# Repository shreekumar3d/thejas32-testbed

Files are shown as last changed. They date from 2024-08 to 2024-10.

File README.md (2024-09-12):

# Status

We're at v1.0, and the board is being tested out.

Do look at the respective directories for hardware and software.

#  Intro

CDAC sells the [ARIES series of boards](https://vegaprocessors.in/devboards/) based on the [THEJAS32 microcontroller](https://vegaprocessors.in/soc/).
The boards can be programmed using the Arduino IDE. Unfortunately, the schematics
of these are not made available.  Documentation about the THEJAS32 SoC itself
is scarce as well, though the chip itself is available for [purchase on robu.in
in single quantity](https://robu.in/product/thejas32-soc-based-microprocessor/).

This project (and follow on work) will try to fill this gap, as I find more.
This is a board design for a learner board based on the THEJAS32
microcontroller. It is the first open source board based on 
the THEJAS32. This is part of a much larger effort to document THEJAS32 
and its ecosystem and make it usuable.

THEJAS32 runs directly on an external clock, offering a single core 100
MHz RISC-V CPU with a IO interfaces - UART, SPI, I2C, PWM and GPIOs.

This board sets up THEJAS32 a test microcontroller, controlled by a Raspberry
Pi Pico.  Some of the IO interfaces are routed to the Pico.  This opens
the door for many types of experimentation and learning, including clock
control, timing, peripheral emulation, etc.  

Useful background and goals for this board are well covered in my [recent talk
at IndiaFOSS 2024](https://youtu.be/-m1KqcOkT5M?t=6345) (video, 25 mins). There
is also a [AtiVEGA hackaday project](https://hackaday.io/project/197724-ativega) page.
Look at hackaday for updates, what's going on in the project, etc.

A somewhat detailed background and intro to the
board is also in [this presentation at ChennaiFOSS 2024 conference](https://www.youtube.com/watch?v=wljsP2YMgHc)
(video, 25 minutes) that I gave earlier this year.

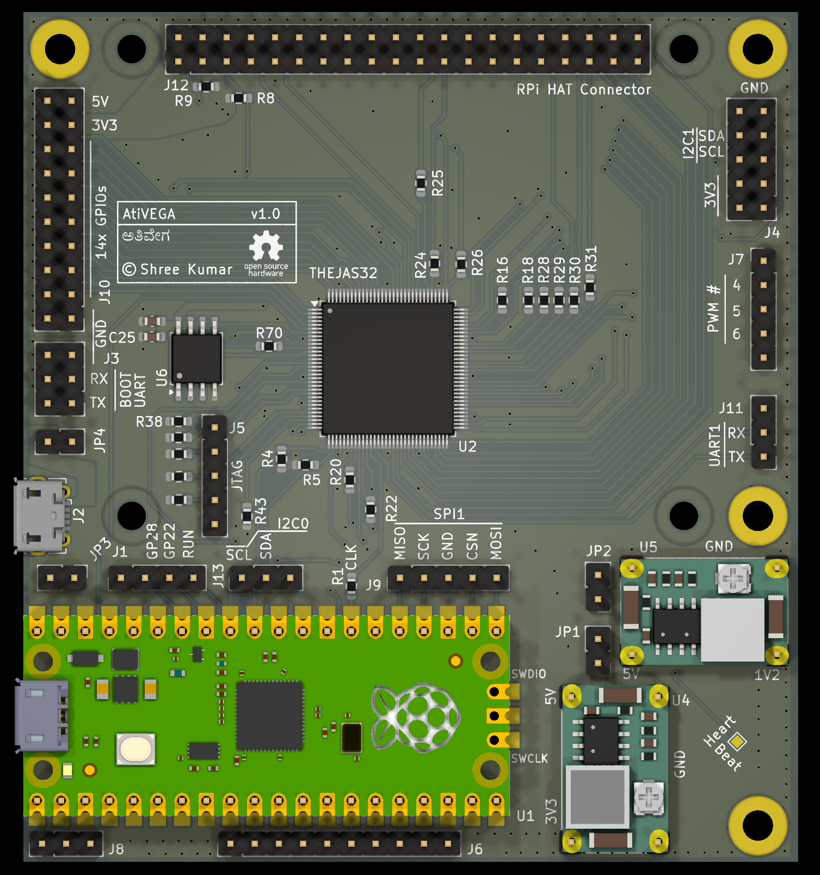
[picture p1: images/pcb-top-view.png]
PCB Top View


This board is designed to be a low cost board, relying on off-the-shelf components
as much as possible.  The goal is to encourage easy assembly without advanced
skills. For this reason, the smallest footprint chosen for passives is 0603.

# Design

The board consists of a few main elements

* THEJAS32 SoC
* 2 MB flash (used by THEJAS32)
* Raspberry Pi Pico
* 2x Mini 360 DC-DC power modules - one to generate core voltage of 1.2V, other for 3.3V

The core of the board consists of

* THEJAS32 SoC
* 2 MB flash

The power and boot cycle of the THEJAS32 ("MCU") is primarily controlled 
using a few pins

* active low RESET can be pulled up by Master Pico to get it out of reset
* System clock is generated from a GPOUT capable pin of the Pico. System 
  clock can thus be generated in many ways
* BOOT_SEL pin is controlled by Pico, allowing boot from SPI flash
  or UART.
* BOOT UART (UART0) is routed to Pico, enabling log capture and 
  programming

Pins and interfaces are broken out into standard 0.1" headers. Dual
row headers are mostly employed. When shorted, the interface gets routed from
the MCU to the RP2040. This enables advanced experimentation, precise timing,
peripheral emulation, co-processing, etc.

Board may be powered using the dedicated micro USB connector(J2) or through
the Pico.  Jumpers JP3 and JP4 decide the source of power. Both jumpers may
also be populated, allowing the Pico to function as a USB host, but care must
be taken not to connect Pico as a USB device in such cases. Refer to the schematic
for more info.

Precise measurement of power draw of the THEJAS32 is also a goal of this board. Jumpers JP2 and JP1 are included for this purpose.

# THEJAS32 IO

All IOs from THEJAS32 are broken out. Software can thus use all the pins. Some details are below; do refer the schematics for complete details.

## UART

Boot UART is available on J3. This can be sent to the Pico for control, by using two jumpers.

J11 breaks out UART1 from THEJAS32.

## Raspberry Pi HAT compatibility

Many Raspberry Pi HATs should be usable with this board, mounted on J12.
THEJAS32 does not have any pin multiplexing. The most commonly used 
functions on the various pins are thus directly assigned, including I2C,
SPI, UART and PWM and GPIOs. Refer the schematics for details.

A full size HAT can be mounted on this board. Additional through holes are 
provided to ensure mechanical support.

## GPIO Breakout

J10 features 14 GPIOs - GPIO17 to GPIO30. States for these can be set one shot, by bit masking.

## I2C and SPI

J4 breaks out I2C1 and SPI0.

J13 provides access to I2C0.  This is also connected to the Pico, for control. Pico can be setup as an I2C slave and respond to I2C transfers initiated by THEJAS32.

Similarly SPI1 is available on J9, also connected to SPI interface on Pico. Pico can be setup as a SPI slave, and respong to transfers initiated by THEJAS32.

## JTAG

J5 breaks out JTAG pins from THEJAS32.  Fun fact: none of the official ARIES boards break out JTAG.

## PWM

PWM pins 4,5,6 are broken out on J7. R32, R33 and R34 can be used to control the current.

# Raspberry Pi Pico

Pico controls the runtime lifecycle of the THEJAS32, via the RESET and CLK pins. BOOT_SEL is also under Pico's control. Note that the Pico is an integral part of the board design, as it provides the clock signal to THEJAS32.

J8 and J6 can be used to interface external electronics directly to Pico. J8 has the debug UART.

A single ADC pin, clock pin (GPIO22) are available as well.

# Tools

Based on KiCAD 8.

# Checkout Instructions

This project uses git submodules. To checkout everything, do:

    git clone --recurse-submodules https://github.com/shreekumar3d/thejas32-testbed.git

Raspberry Pi Pico footprint is a submodule.  If you don't go this, you'll not
see the nice Pico in the 3D preview.

# Credits

* [RPi Pico Symbool and Footprint](https://github.com/ncarandini/KiCad-RP-Pico)
* [Mini 360 Step Down Converter Footprint](https://github.com/rayvburn/KiCad)

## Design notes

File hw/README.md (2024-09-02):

# AtiVEGA Board

AtiVEGA is designed with KiCAD 8. The entire design is available here - both schematics and layout. Plus complete documentation, design rationale, etc.

High quality documentation is an important goal for this project. Obscurity is not. [THEJAS32](https://vegaprocessors.in/soc/) is a bit of a black box, and this is the tool to demistify it, learn from it and understand hardware at various levels. If you have a question, feel free to ask!

The *raison d'etre* of this board is to serve as a learning board for RISC-V at the PCB (board) level, the ISA level and the sillicon level.  It is designed for desk usage.

Raspberry Pi Pico is chosen as the system master for its excellent documentation, flexibility, capabilities and high performance. It is wired as a coprocessor, enabling many use cases.

As of this writing (September 2024), this is the only open source board that includes the THEJAS32.  Not just that - it is the only known board apart from CDAC's [ARIES boards](https://vegaprocessors.in/devboards/).  It is also the only board that breaks out the JTAG signals - the ultimate attempt to demistify the *Sarkaari* SoC! Open source trumps RTI (Right to Information) - FTW!

THEJAS32 is abbreviated to T32 in the rest of the document.

## PCB Design

The PCB is designed, and choice of components, is made to ease manual assembly.  That said, T32 - the main microcontroller, or more accurately, the *device under test(DUT)* has a LQFP128 footprint - with its pins spaced 0.5mm apart.  This is typically solderable with the aid of a magnifier.  The board also uses relatively fine surface mount components - resistors and capacitors are 0603.  The flash IC is an easier SOIC-8.  Rest are all through hole components - mostly connectors, the Raspberry Pi Pico and the Mini360 DCDC Power Modules.

The design emphasizes modularity, and relies on locally procurable components.  The idea is that anybody should be able to just get the PCB and the components and assemble the board. I could have included DC-DC regulators on the board, but I have chosen not to.  I believe this allows you to experiment with ease. Some examples:

 1. T32's core voltage is 1.2V and IO voltage is 3.3V.  Upper and lower limits are not know (yet!). Using the trimpot on the DCDC modules, these voltages can be changed. Not only will this allow me to find the limits (expecting magic smoke *at-least* once!), but it also allows anyone to study things like impact of system clock on power consumption, leakage current, etc.
 2. [Raspberry Pi Pico](https://www.raspberrypi.com/documentation/microcontrollers/pico-series.html) is used by default, but the board isn't specific to it, as there are a few compatbile options.  Need WiFi ? Use Pico W ! Need more performance - there's the Pico 2 now! Pico 2's selectable RISC-V/ARM cores means you can benchmark and compare two RISC-V implementations on one board - the [Hazard3 - RV32IMACZb*](https://github.com/Wren6991/Hazard3) and [ET1031 on T32 - RV32IM](https://vegaprocessors.in/thejas32.php). How cool is that ?

The PCB is designed as a 4 layer PCB, with the following layers:

 1. Signal - Top Layer
 2. GND
 3. Power
 4. Signal - Bottom Layer

# Simplified Schematics

For illustration, here is a simplified schematic. Some components or connectors are omitted for brevity.  They are explained later, as required.

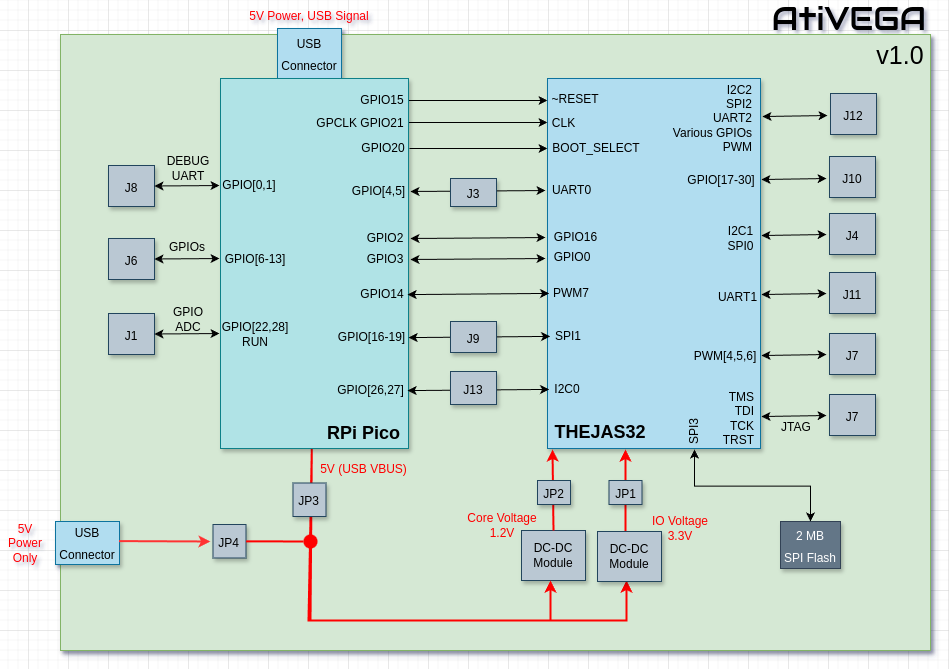
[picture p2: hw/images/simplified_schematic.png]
AtiVEGA Simplified Schematics


## Powering the Board

### Single Cable Operation

AtiVEGA can be powered by a single USB micro B cable, connected to the Pico. For this,

 1. Populate jumpers JP4, JP1 and JP2.
 2. Ensure JP3 is open

### Two Cable Operation

If you wish to measure the power consumed by the T32 section separately:

 1. Populate JP3, JP1 and JP2.
 2. Ensure JP4 is populated
 3. Connect both USB connectors to a host PC/5V power supply. Typically you would connect the Pico to a host PC for status monitoring, but this is strictly not essential.  You could choose to use J8 to monitor debug messages over UART.

Note that measuring power in series with JP3 will measure the power of T32, any components connected on the board (apart from the Pico), and it will include the overhead of the DCDC converters.

### Fine Grained Power Measurement

To avoid the DCDC connectors, you can connect a real power supply to the appropriate points on JP1(3.3V), JP2(1.2V) and JP3(5V).  This gives the most accurate power reading, at the cost of more equipment. Alternatively, just measure power in series using modules such as INA219.

## THEJAS32 <-> Pico

The Pico is the system master and a co-processor.  It is the first component on the board that powers on and becomes active.

The Pico is directly connected to T32's RESET_N, and CLK lines. GPIO21 is a GPCLK capable pin, and can drive T32's system clock at system clock speeds of the Pico - which is known to be massively overclockable...  How much can the T32 handle ?

T32 runs a bootloader from an internal bootrom (I am guessing, the bootrom part is not documented). The behaviour of this depends on the BOOT_SELECT line, which is controlled by the Pico.  If BOOT_SELECT is *low*, T32 loads code from the SPI flash (interface SPI3).  To support this, the board includes a 2MB SPI flash. If BOOT_SELECT is *high*, T32 boots from UART, using an XMODEM+CRC protocol.  T32's boot UART interface, UART0 is connected to GPIO4 and GPIO5 of the Pico, through the header JP3. This allows you to either tap out the lines for external examination, or route them to the Pico  the recommended default.

Note that irrespective of the state of BOOT_SELECT, T32 puts out the following fixed header over UART before taking action according to BOOT_SELECT.

    +-----------------------------------------------------------------------------+
    |           VEGA Series of Microprocessors Developed By C-DAC, INDIA          |
    |     Microprocessor Development Programme, Funded by MeitY, Govt. of India   |
    +-----------------------------------------------------------------------------+
    | Bootloader, ver 1.0.0 [  (hdg@cdac_tvm) Tue Dec  15 16:50:32 IST 2020 #135] |
    |                                                                             |
    |  ___    _________________________          ISA  : RISC-V [RV32IM]           |
    |  __ |  / /__  ____/_  ____/__    |                                          |
    |  __ | / /__  __/  _  / __ __  /| |         CPU  : VEGA ET1031               |
    |  __ |/ / _  /___  / /_/ / _  ___ |                                          |
    |  _____/  /_____/  \____/  /_/  |_|         SoC  : THEJAS32                  |
    +---------------------------------------+-------------------------------------+
    |         www.vegaprocessors.in         |             vega@cdac.in            |
    +---------------------------------------+-------------------------------------+

After T32 finishes booting, this UART can be used to communicate between the applications running on the T32 and the Pico.

GPIO[0,16] of T32 are routed to GPIO[2,3] of Pico.  These can be used to intimate each other of actions to be taken.  As a simple example, T32 could use GPIO0 to control the LED on the Pico, with the Pico's involvement. Similarly, the on-board button on the Pico could be used to take appropriate action on T32. Note that proper usage will require setting the appropriate direction on both sides of the GPIO.

T32's PWM7 pin is routed to Pico's GPIO14.  This can be used to test, validate and characterize the PWM capabilities of the T32.  Additionally, as a PWM with 100% duty cycle, it can be used as a GPIO output from T32 to Pico.

Similarly, T32's SPI1 and I2C0 interfaces are also routed to Pico.  T32's hardware interfaces are master only.  Luckily, Pico supports slave modes for both SPI and I2C. With appropriate software, Pico can even emulate actual hardware, and even initiate external action (over USB or WiFi/BT in case of Pico W).

Since the board uses standard headers, you can even use jumper wires to connect other IOs between Pico and T32.

Overall, many useful possibilities are created by these interconnections, and these  will be further explored in the 'sw' directory.

## External Hardware Connections to THEJAS32

### GPIOs

14 GPIOs - GPIO[17-30] are available on J10 (it also includes 3.3V, 5V and GND).

These GPIOs are chosen for a specific purpose - they are controlled by a single register, thus their states may be changed/sampled with a single instruction. 

When used as output, GPIO16 (connected to Pico) and GPIO31 (on the HAT connector) could also be impacted by the instruction, and appropriate care can be taken if needed.

### UART

T32's UART1 interface is routed to J11.

### I2C

T32's I2C1 interface is connected to J4.  Pull up resistors R6 and R7 are on the bottom side of the board.

### SPI

T32's SPI0 interface is routed to J4. Series resistors R16 and R18 for clock and MOSI line are placed close to T32 on the top side, for tuning, if necessary.

### PWM

3 PWM pins, PWM 4,5 and 6 are routed to J7. R32, R33 and R34 are series resistors on these lines. T32's pins support 12mA per IO pin, which is sufficient to drive LEDs. Ensure you use appropriate current limiting resistors, or replace the ones on the board.

### Raspberry Pi HAT compatibility

Raspberry Pi HATs can be plugged in to J12 and used. pHATs and full sized HATs are mechanically compatible.  For full sized HATs, two through holes are provided for mechanical support and grounding.

T32 does not have any kind of pin multiplexing.  Thus, this board cannot support all the pin multiplexing as implemented on a Raspberry Pi. That said, I have looked at the most common uses of the pins in HATs (from [pinout.xyz](https://pinout.xyz/)), and pins have been assigned to maximize compatibility.  Most commonly used functions on specific pins (I2C and SPI) have been included.

Here is the detailed pin mapping:

|RPi Pin Mapping |T32 Pin  |HAT Pin No|HAT Pin No|T32 Pin |RPi Pin Mapping |
|---|---|---|---|---|---|
|3V3 Power | | 1 | 2 | |5V Power |
|GPIO 2(I2C1 SDA)  |I2C2_SDA | 3 | 4 | |5V Power |
|GPIO 3(I2C1 SCL)  |I2C2_SCL | 5 | 6 | |Ground |
|GPIO 4(GPCLK0) |GPIO 31  | 7 | 8 |UART2_TX|GPIO 14(UART TX)  |
|Ground | | 9 | 10 |UART2_RX|GPIO 15(UART RX)  |
|GPIO 17 |GPIO 1 | 11 | 12 |PWM0 |GPIO 18(PCM CLK)  |
|GPIO 27 |GPIO 2 | 13 | 14 | |Ground |
|GPIO 22 |GPIO 3 | 15 | 16 |GPIO 4  |GPIO 23 |
|3V3 Power | | 17 | 18 |GPIO 5  |GPIO 24 |
|GPIO 10(SPI0 MOSI)|SPI2_MOSI| 19 | 20 | |Ground |
|GPIO 9(SPI0 MISO) |SPI2_MISO| 21 | 22 |GPIO 6  |GPIO 25 |
|GPIO 11(SPI0 SCLK)|SPI2_CLK | 23 | 24 |SPI2_CSN|GPIO 8(SPI0 CE0)  |
|Ground | | 25 | 26 |GPIO 7  |GPIO 7(SPI0 CE1)  |
|GPIO 0(EEPROM SDA)|GPIO 8 | 27 | 28 |GPIO 9  |GPIO 1(EEPROM SCL)|
|GPIO 5 |GPIO 10  | 29 | 30 | |Ground |
|GPIO 6 |GPIO 11  | 31 | 32 |PWM1 |GPIO 12(PWM0) |
|GPIO 13(PWM1) |PWM2 | 33 | 34 | |Ground |
|GPIO 19(PCM FS) |PWM3 | 35 | 36 |GPIO 12 |GPIO 16 |
|GPIO 26 |GPIO 13  | 37 | 38 |GPIO 14 |GPIO 20(PCM DIN)  |
|Ground | | 39 | 40 |GPIO 15 |GPIO 21(PCM DOUT) |

HAT's EEPROM SDA and SCL are connected to T32 GPIO 8 and 9. I am not sure if EEPROM is used extensively.  If required, I2C access would need to be achieved via bit banging these pins. There are no pull-up options on the board to facilitate this, though. Should be enough for EEPROM, though.

A large number of HATs/pHATs use I2C, and some use SPI (common for displays). These should be largely compatible.  For a complete compatibility list, check the end of this document.

## External Hardware Connections to Pico

Unused pins on the Pico are broken out into specific headers to ease interfacing with external hardware.

### Debug UART

Pico's GPIO0 and 1 are connected to J8.  These are typically used as the debug UART pins on the Pico - supported by hardware uart0.

### GPIOs

8 GPIOs - GPIO 6-13 are routed to J6, with their pins directly in-line with the Pico. These can be used to interface external hardware in any number of flexible ways.

Similarly, GPIO22 and GPIO28 are routed to J1.

### ADC

Pico's GPIO28 can be used as an ADC pin - and it is broken out to J1.

# RPi HAT/pHAT Compatibility

Here is a hardware compatibility table for HATs from [pinout.xyz](https://pinout.xyz).

Note that this is not an indicator of software support.  The Tested column should be your definitive guide.  If you test something and it works, do let me know!

I have a few HATs and pHATs, which I will test and update below. This table mostly reflects grunt work I do that I don't want to waste.

|SN |Manufacturer |HAT Name |Form Factor|Compatible|Tested?|Notes |
|---|---|---|---|---|---|---|
|1  |AB Electronics UK|1 Wire Pi Plus |HAT |Yes | | |
|2  |AB Electronics UK|1 Wire Pi Zero |pHAT |Yes | | |
|3  |Adafruit |16x2 Character LCD |pHAT |Yes | | |
|4  |Waveshare |2.13 Inch E-Ink Display pHAT |pHAT |Yes | | |
|5  |PlasmaDan |30 A Relay HAT |HAT |Yes | | |
|6  |PiHut |3D XMAS Tree |HAT |No | | |
|7  |Sixfab |3G/4G/LTE Base Shield |HAT |Yes | | |
|8  |Sixfab |3G/4G/LTE Base Shield V2 |HAT |No | |UART pin mismatch |
|9  |AB Electronics UK|ADC Differential Pi |pHAT |Yes | | |
|10 |AB Electronics UK|ADC Pi |pHAT |Yes | | |
|11 |AB Electronics UK|ADC-DAC Pi Zero |pHAT |Yes | | |
|12 |Google |AIY Vision Bonnet |pHAT |Unknown | |Check again |
|13 |Google |AIY Voice Bonnet |pHAT |No | |No I2S support |
|14 |Google |AIY Voice HAT |HAT |No | |No I2S support |
|15 |JustBoom |Amp HAT |HAT |No | |No I2S support |
|16 |JustBoom |Amp Zero |pHAT |No | |No I2S support |
|17 |RasPIO |Analog Zero |pHAT |Yes | | |
|18 |PlasmaDan |Appliance HAT |HAT |Yes | | |
|19 |PlasmaDan |Appliance HAT Mini |pHAT |Yes | | |
|20 |Adafruit |Arcade Bonnet |pHAT |No | |No I2S support |
|21 |Pimoroni |Audio Amp SHIM |pHAT |No | |No I2S support |
|22 |Pimoroni |Automation HAT |HAT |Possible  | |Use PWM as GPIO |
|23 |Pimoroni |Blinkt! |pHAT |No | |Check again |
|24 |Pimoroni |Breakout Garden HAT |HAT |Yes | |Check again |
|25 |Pimoroni |Breakout Button SHIM |pHAT |Yes | | |
|26 |PiHut |CamJam EduKit 3 motor controller board |pHAT |Yes | |Check GPIO usage |
|27 |Josip Medved |Canaka |HAT |Yes | | |
|28 |Adafruit |Capacitive Touch HAT |HAT |Yes | | |
|29 |Paser |Carberry |HAT |No | |LIRC pin |
|30 |Sixfab |Raspberry Pi Cellular IoT Application HAT|HAT |No | |UART pin mismatch |
|31 |ModMyPi |Christmas Tree Star | |No | |SPI pins can't be used as GPIO |
|32 |Element14 |Cirrus Logic Audio Card |HAT |No | |No audio support |
|33 |Google |Coral Environment Sensing Board |pHAT |No | |PWM pin can't be used as GPIO input|
|34 |PlasmaDan |CTRL HAT |HAT |Yes | | |
|35 |4tronix |cube:bit Base |HAT |No | |PWM pin can't do neopixel timing |
|36 |JustBoom |DAC HAT |HAT |No | |No audio support |
|37 |JustBoom |DAC Zero |pHAT |No | |No audio support |
|38 |Adafruit |DC & Stepper Motor HAT |HAT |Yes | | |
|39 |Raspihats |DI6acDQ6rly I2C-HAT |HAT |Yes | | |
|40 |JustBoom |Digi HAT |HAT |No | |No audio support |
|41 |JustBoom |Digi Zero |pHAT |No | |No audio support |
|42 |Kertatuote |Disco HAT | |No | |PWM pin can't be used as GPIO input|
|43 |Pimoroni |Display HAT Mini |pHAT |Maybe | |Use GPIO 7 as SPI CS |
|44 | | | | | | |

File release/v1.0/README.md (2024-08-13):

This is the first gerber release to production.

I am excited as this will be my second personal PCB, ever! The first one was an
automatic water control design for drip irrigation, built with the MSP430.

After some comparisons, I ended up using JLCPCB for the manufacturing. Gave them
ativega-v1.zip. Opted for impedance control, and no marks on the PCB. Also
included the production confirmation for peace of mind.

The top view, bottom view of the PCB generated by JLCPCB, as well as the
manufacturing gerbers are in the corresponding directory.

The first batch is 10 boards. $30.90 for boards, $35.20 for shipping, totalling
$66.10.

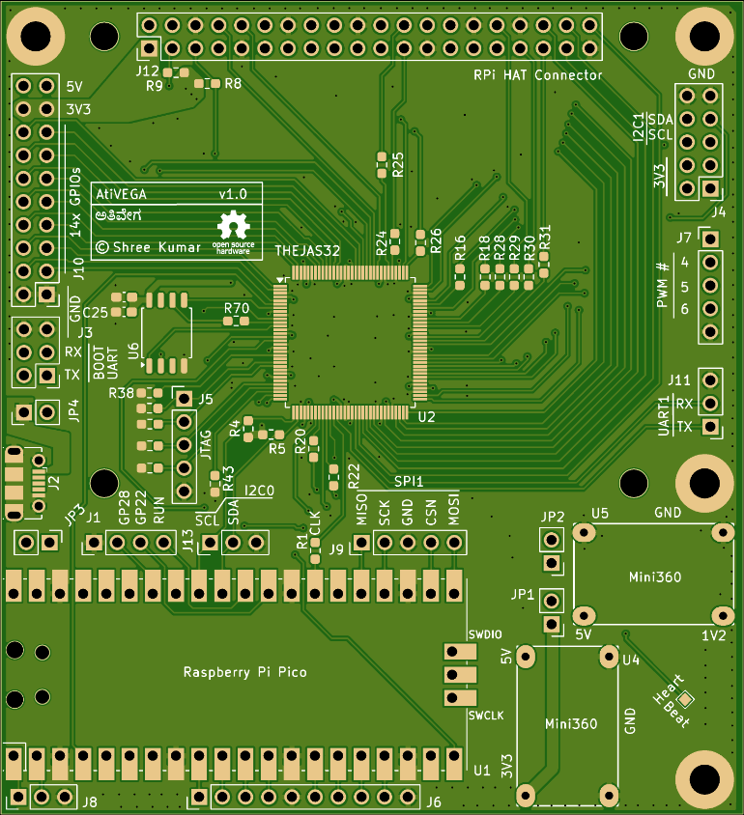
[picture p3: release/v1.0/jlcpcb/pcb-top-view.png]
Top View


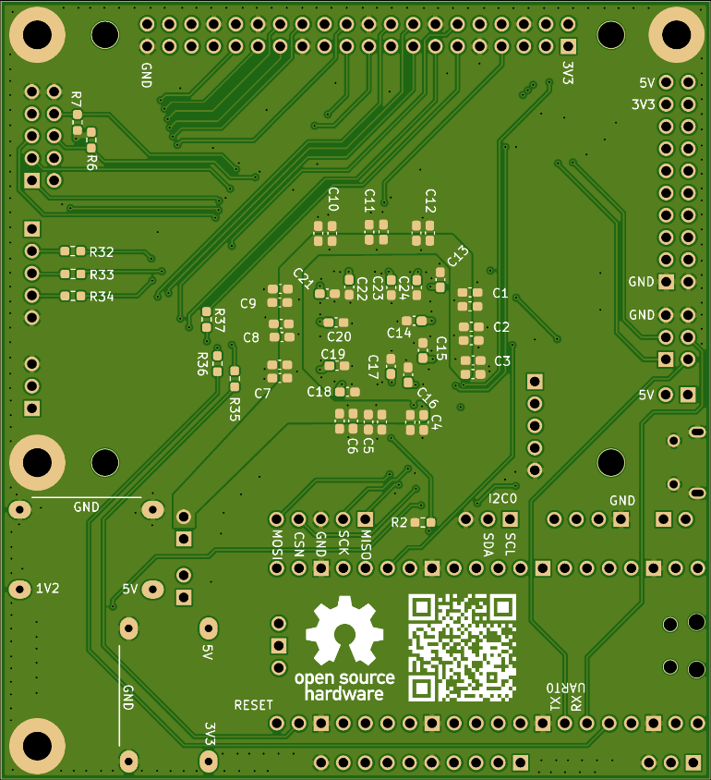
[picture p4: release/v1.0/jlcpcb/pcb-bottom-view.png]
Bottom View


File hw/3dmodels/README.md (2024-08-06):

MicroUSB connector Molex 105017-0001
3dmodel : 1050170001.stp
Source : https://www.molex.com/en-us/products/part-detail/1050170001

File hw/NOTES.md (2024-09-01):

Hardware is designed with KiCAD v8.

If kicad complains about missing freemono font, install the package
fonts-freefont-ttf

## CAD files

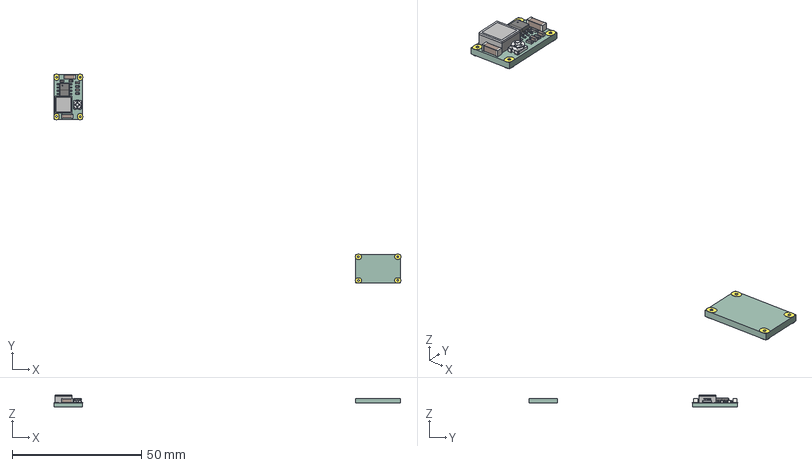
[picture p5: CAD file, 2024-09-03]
hw/3dmodels/mini360-model.step
134.4 x 80.9 x 4.63 mm
C_0603_1608Metric
R_0603_1608Metric
R_0603_1608Metric001
R_0603_1608Metric002
C_0603_1608Metric001
C_0603_1608Metric002
C_1806_4516Metric001
mini360_pad_1 x 2
mini360_pad_2 x 2
mini360_pad_3 x 2
mini360_pad_4 x 2
mini360_pad_5 x 2
mini360_pad_6 x 2
mini360_pad_7 x 2
mini360_pad_8 x 2
mini360_pad_9 x 2
mini360_pad_10 x 2
mini360_pad_11 x 2
mini360_pad_12 x 2
mini360_PCB x 2
C_1806_4516Metric
EVM-3E
729b0bae-9266-11ed-9e62-a0cec80452fd_part x 4
729b0e92-9266-11ed-9e62-a0cec80452fd_part x 5
729b0e92-9266-11ed-9e62-a0cec80452fd_part001 x 5
729b0e92-9266-11ed-9e62-a0cec80452fd_part002 x 5
729b0e92-9266-11ed-9e62-a0cec80452fd_part003 x 5
729b0e92-9266-11ed-9e62-a0cec80452fd_part004 x 5
729b0e92-9266-11ed-9e62-a0cec80452fd_part005 x 5
729b0e92-9266-11ed-9e62-a0cec80452fd_part006 x 5
729b0e92-9266-11ed-9e62-a0cec80452fd_part007 x 5
729b1108-9266-11ed-9e62-a0cec80452fd_part x 4

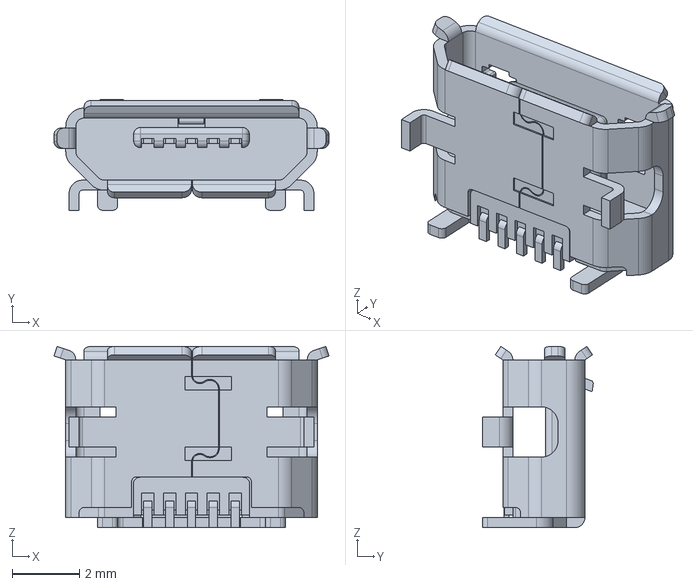
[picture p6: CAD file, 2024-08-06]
hw/3dmodels/1050170001.stp
8.20 x 3.30 x 5.40 mm

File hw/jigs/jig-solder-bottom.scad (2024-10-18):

// Auto generated file by jig-gen, the awesome automatic
// jig generator for your PCB designs.
//
// Input board file   : ../thejas32-testbed/hw/thejas32-testbed.kicad_pcb
// Configuration file : ../thejas32-testbed/hw/jigs/solder-bottom.toml
//
// Complete configuration file is embedded at the end of this
// file.

// { These are configurable parameters
// you can tweak these here and count on
// openscad magic to do show you the result
// right away!

// Tesellate finer than 3D printer can print
$fs = 0.05;

// Gap for components to slide into their shell,
// on all sides in the horizontal plane (in mm)
shell_gap = 0.1;
                
// Thickness of shells (in mm)
shell_thickness = 0.8;

// Thickness of PCB (in mm)
pcb_thickness=1.8;

// Clearance between typical shells and PCB
// Allows you to check and confirm component fit
shell_clearance=1.0;

// Shells jet out of the PCB by this much
// (Mostly a visualization/debug aid)
shell_protrude=1;

// Thickness of base (in mm)
// base provides a holding structure for the shells
// and connects it to the frame (on which the board
// sits)
base_thickness = 1.0;

// Line width in the mesh
mesh_line_width = 1.6;

// By default, we generate a base with a delaunay
// frame holding the shells together.
//
// Sometimes you just need a solid base - e.g. to
// put some text - like PCB info, version
// and even stuff like qrcodes! For these you
// mostly need a solid base. Set this is non-zero
// if that's what you need.
base_is_solid = 0;

// Board will sit on a lip, close to mounting holes
// Lips that lie in a square of this size (in mm)
// will be part of the model.
lip_size=15;

// Gap (in mm) between board edge and slot on which the board sits
pcb_gap=0.3;

// Width of the lip (in mm) on which the board rests
pcb_overlap=0.5;

// PCB holder's wall thickness (in mm)
// This will be the thickness after the gap
pcb_holder_perimeter=1.6;

// The board can have a (lower) perimeter for added
// strength/aesthetics.  Perimeter height is above
// the base, and in mm
pcb_perimeter_height = 2;

// } End of configurable parameters

// { START : Computed Values

// Height of the tallest component on the top side
topmost_z=8.53948;
// Height of the individual components
max_z_J7_0=8.53948; //3D Model: ${KICAD8_3DMODEL_DIR}/Connector_PinHeader_2.54mm.3dshapes/PinHeader_1x05_P2.54mm_Vertical.wrl
max_z_J5_0=8.53948; //3D Model: ${KICAD8_3DMODEL_DIR}/Connector_PinHeader_2.54mm.3dshapes/PinHeader_1x05_P2.54mm_Vertical.wrl
max_z_J9_0=8.53948; //3D Model: ${KICAD8_3DMODEL_DIR}/Connector_PinHeader_2.54mm.3dshapes/PinHeader_1x05_P2.54mm_Vertical.wrl
max_z_J1_0=8.53948; //3D Model: ${KICAD8_3DMODEL_DIR}/Connector_PinHeader_2.54mm.3dshapes/PinHeader_1x04_P2.54mm_Vertical.wrl
max_z_J3_0=8.53948; //3D Model: ${KICAD6_3DMODEL_DIR}/Connector_PinHeader_2.54mm.3dshapes/PinHeader_2x03_P2.54mm_Vertical.wrl
max_z_J6_0=8.53948; //3D Model: ${KICAD8_3DMODEL_DIR}/Connector_PinHeader_2.54mm.3dshapes/PinHeader_1x10_P2.54mm_Vertical.wrl
max_z_JP3_0=8.53948; //3D Model: ${KICAD8_3DMODEL_DIR}/Connector_PinHeader_2.54mm.3dshapes/PinHeader_1x02_P2.54mm_Vertical.wrl
max_z_JP2_0=8.53948; //3D Model: ${KICAD6_3DMODEL_DIR}/Connector_PinHeader_2.54mm.3dshapes/PinHeader_1x02_P2.54mm_Vertical.wrl
max_z_J13_0=8.53948; //3D Model: ${KICAD8_3DMODEL_DIR}/Connector_PinHeader_2.54mm.3dshapes/PinHeader_1x03_P2.54mm_Vertical.wrl
max_z_U5_0=8.53948; //3D Model: ${KICAD8_3DMODEL_DIR}/Connector_PinHeader_2.54mm.3dshapes/PinHeader_1x01_P2.54mm_Vertical.wrl
max_z_U5_1=8.53948; //3D Model: ${KICAD8_3DMODEL_DIR}/Connector_PinHeader_2.54mm.3dshapes/PinHeader_1x01_P2.54mm_Vertical.wrl
max_z_U5_2=8.53948; //3D Model: ${KICAD8_3DMODEL_DIR}/Connector_PinHeader_2.54mm.3dshapes/PinHeader_1x01_P2.54mm_Vertical.wrl
max_z_U5_3=8.53948; //3D Model: ${KICAD8_3DMODEL_DIR}/Connector_PinHeader_2.54mm.3dshapes/PinHeader_1x01_P2.54mm_Vertical.wrl
max_z_U4_0=8.53948; //3D Model: ${KICAD8_3DMODEL_DIR}/Connector_PinHeader_2.54mm.3dshapes/PinHeader_1x01_P2.54mm_Vertical.wrl
max_z_U4_1=8.53948; //3D Model: ${KICAD8_3DMODEL_DIR}/Connector_PinHeader_2.54mm.3dshapes/PinHeader_1x01_P2.54mm_Vertical.wrl
max_z_U4_2=8.53948; //3D Model: ${KICAD8_3DMODEL_DIR}/Connector_PinHeader_2.54mm.3dshapes/PinHeader_1x01_P2.54mm_Vertical.wrl
max_z_U4_3=8.53948; //3D Model: ${KICAD8_3DMODEL_DIR}/Connector_PinHeader_2.54mm.3dshapes/PinHeader_1x01_P2.54mm_Vertical.wrl
max_z_J12_0=8.53948; //3D Model: ${KICAD6_3DMODEL_DIR}/Connector_PinHeader_2.54mm.3dshapes/PinHeader_2x20_P2.54mm_Vertical.wrl
max_z_J2_0=2.5749970500000003; //3D Model: ${KIPRJMOD}/3dmodels/1050170001.wrl
max_z_JP4_0=8.53948; //3D Model: ${KICAD8_3DMODEL_DIR}/Connector_PinHeader_2.54mm.3dshapes/PinHeader_1x02_P2.54mm_Vertical.wrl
max_z_J8_0=8.53948; //3D Model: ${KICAD8_3DMODEL_DIR}/Connector_PinHeader_2.54mm.3dshapes/PinHeader_1x03_P2.54mm_Vertical.wrl
max_z_JP1_0=8.53948; //3D Model: ${KICAD6_3DMODEL_DIR}/Connector_PinHeader_2.54mm.3dshapes/PinHeader_1x02_P2.54mm_Vertical.wrl
max_z_J10_0=8.53948; //3D Model: ${KICAD6_3DMODEL_DIR}/Connector_PinHeader_2.54mm.3dshapes/PinHeader_2x10_P2.54mm_Vertical.wrl
max_z_J4_0=8.53948; //3D Model: ${KICAD8_3DMODEL_DIR}/Connector_PinHeader_2.54mm.3dshapes/PinHeader_2x05_P2.54mm_Vertical.wrl
max_z_J11_0=8.53948; //3D Model: ${KICAD8_3DMODEL_DIR}/Connector_PinHeader_2.54mm.3dshapes/PinHeader_1x03_P2.54mm_Vertical.wrl
max_z_U1_1=7.00024; //3D Model: ${KICAD8_3DMODEL_DIR}/Connector_PinSocket_2.54mm.3dshapes/PinSocket_1x20_P2.54mm_Vertical.wrl
max_z_U1_2=7.00024; //3D Model: ${KICAD8_3DMODEL_DIR}/Connector_PinSocket_2.54mm.3dshapes/PinSocket_1x20_P2.54mm_Vertical.wrl
// } END : Computed Values
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

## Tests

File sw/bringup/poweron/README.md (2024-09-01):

# Basic Power On Test

This sample does a basic power on the THEJAS32 on the AtiVEGA board.  The RP2040 microcontroller on the Pico serves as the driver.

## AtiVEGA Architecture

AtiVEGA includes the THEJAS32 microcontroller and a Raspberry Pi Pico.  

Typical microcontrollers use a medium frequency crystal (few MHz) as a clock source. They include an internal oscillator and PLL to boost this frequency manifold.  Raspeberry Pi Pico is based on the RP2040 microcontroller.  This microcontroller runs at 125 MHz or more, using a PLL running from a 12 MHz crystal.

Unlike the RP2040, THEJAS32 need an oscillator capable of driving a 3.3V clock! ARIES boards include a dedicated oscillator, part number [SIT8008AC-33-33E-100.000000](https://www.sitime.com/parts/sit8008ac-73-33e-100000000) for this purpose.  This generates the system clock for THEJAS32 - a fixed 100 MHz.  If we do include this part, we would adds to the cost and power consumption of AtiVEGA. We can do better than that.

Instead of a discrete oscillator, we use the a GPCLOCK pin of the RP2040 as the clock source.  This pin can be driven by the RP2040 at a very high speed. How fast ? At a maximum rate of the system clock of the RP2040. That's 125 MHz typical.  And more, if you overclock the microcontroller.

AtiVEGA also connect the RESET pin and BOOT_SELECT of THEJAS32 to RP2040 GPIO pins.  THEJAS32 checks tthe BOOT_SELECT pin on power up.  If it is low, the chip boots from the SPI flash.  If it is high, the chip boots from UART.  In either cases, THEJAS32 uses the boot UART to show the status and/or provide the option of uploading code.

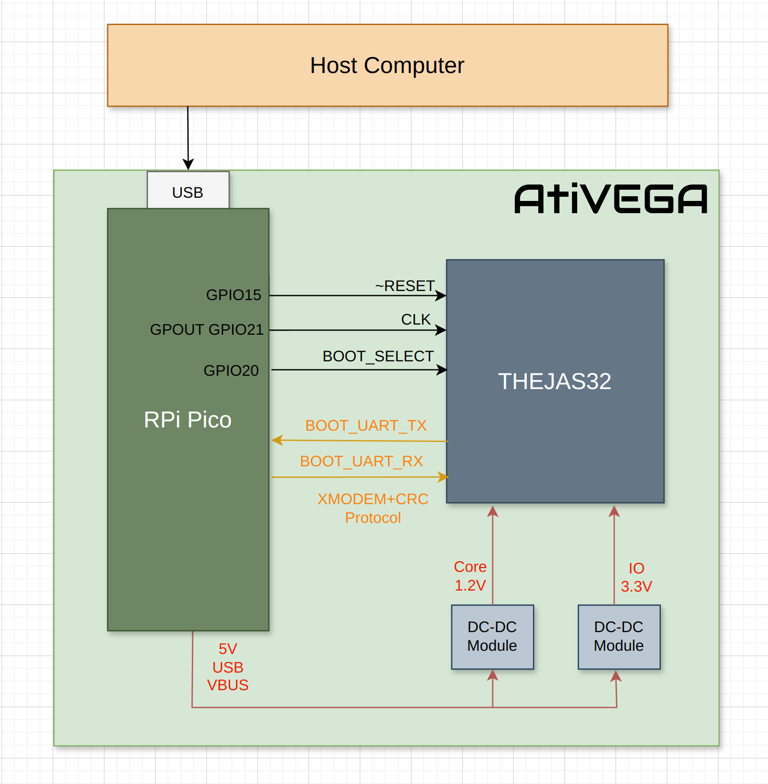
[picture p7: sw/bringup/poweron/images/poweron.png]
Power On Board Schematic


Overall, THEJAS32 runtime life cycle is controlled by RP2040 in the Pico.  And hence, the entire lifecycle is software driven. And you can control it.  This sample shows how.

## Source Code

This is a Pico C/C++ SDK project.  When you build it, you will get poweron.uf2. Push it into the Pico to activate it.

poweron.c has all the power on steps mentioned below.  It is well commented. System clock is configured in CMakeLists.txt, which is also the build script for the project.

## Power On Method

Before powering on, first connect GPIO30 on header J10 to 3.3V with a jumper.  THEJAS32 uses this to configure the baud rate of the Boot UART interface.

Pico will restart and start running the code.  First, THEJAS32 is placed in reset by setting the GPIO low.  BOOT_SELECT line is pulled high to indicate UART boot. Then a 100 MHz clock is provided via GPIO21.  THEJAS32 is then taken out of reset, by setting the GPIO high.

In response, THEJAS32 boots.  First, it prints out a header. Then it waits for a software image over UART. This project does not implement the capability of uploading a software image.  Only basic booting is illustrated.

You can use your favourite terminal emulator (e.g. minicom) to look at the UART activity. If you see messages like below - then congratulations, you did everything right !

    =========================================================
    AtiVEGA ready to power-on THEJAS32
    Communicating with THEJAS32 at UART baud=195312
                                  (requested:195312)
    Powering on with clock=100000000 Hz _after_ 3 seconds!
    THEJAS32's boot log will follow after the next line
    =========================================================

    +-----------------------------------------------------------------------------+
    |           VEGA Series of Microprocessors Developed By C-DAC, INDIA          |
    |     Microprocessor Development Programme, Funded by MeitY, Govt. of India   |
    +-----------------------------------------------------------------------------+
    | Bootloader, ver 1.0.0 [  (hdg@cdac_tvm) Tue Dec  15 16:50:32 IST 2020 #135] |
    |                                                                             |
    |  ___    _________________________          ISA  : RISC-V [RV32IM]           |
    |  __ |  / /__  ____/_  ____/__    |                                          |
    |  __ | / /__  __/  _  / __ __  /| |         CPU  : VEGA ET1031               |
    |  __ |/ / _  /___  / /_/ / _  ___ |                                          |
    |  _____/  /_____/  \____/  /_/  |_|         SoC  : THEJAS32                  |
    +---------------------------------------+-------------------------------------+
    |         www.vegaprocessors.in         |             vega@cdac.in            |
    +---------------------------------------+-------------------------------------+

    Transfer mode  : UART XMODEM

    IRAM           : [0x200000 - 0x23E7FF] [250 KB]

    Please send file using XMODEM and then press ENTER key.

    ==> Ready to receive image 66275 microseconds after power on.
    ==> First char was received 6 microseconds after power on.

    CCCCCCCCCCCCCCCCCCCCCCCCCCCCCCCCCCCCCCCCCCCC

Note that the two lines beginning with "==>" are printed by this project's code.  Everything else above is output by THEJAS32 over UART.

## Slowing down THEJAS32

THEJAS32's clock speed can be *reduced* by changing T_CLK_DIV in poweron.c. A divider of 2 will run THEJAS32 at 50 MHz, 4 at 25 MHz, and 40 at 2.5 MHz.  Higher the divider, lower the execution speed.  You'll see the UART text slowly coming up as you increase the divider.  Note that changing the clock will indirectly change the UART baud rate as well.

How low can you go ?

## Overclocking THEJAS32

THEJAS32 is described as a 100 MHz RISC-V microcontroller.  But how fast can it really run ?

How about a cool 172 MHz ? Check CMakeLists.txt, rebuild, flash and enjoy!

## Monitoring the Heart Beat

THEJAS32 has a unique debugging feature - a HEART BEAT pin. CDAC's ARIES boards connect an LED to that.  AtiVEGA doesn't - we just route it to a pad on the board. This pin toggles at a very slow rate compared to the system clock - around 2.5 Hz with a 100 MHz system clock.  This is a 3.3V signal, and can be viewed with a simple logic analyzer (salea logic or clones) or an oscilloscope.

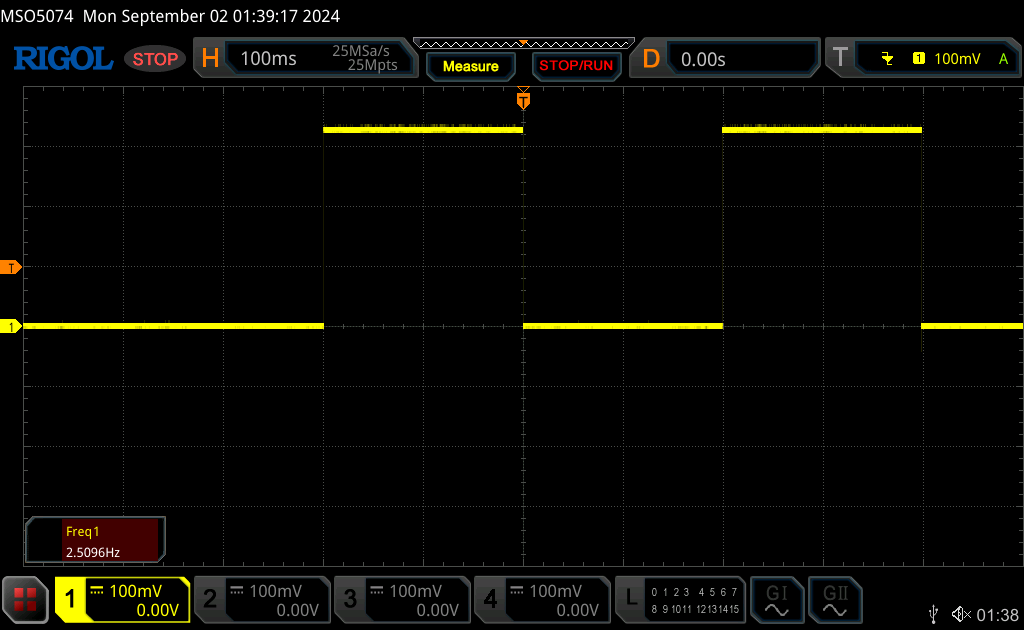
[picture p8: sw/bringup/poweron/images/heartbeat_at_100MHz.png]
Heart Beat signal with system clock=100 MHz


In hindsight, I should have made it at-least a through hole pin to make it easier to connect to the RP2040 with a jumper wire. Perhaps in the second revision....

## Lab Exercises

Work out these...

 1. What's the slowest clock speed at which you can run THEJAS32 ?
 2. What is the fastest clock speed at which you can run THEJAS32 ?
 3. Do you see UART messages at the slowest/fastest clock rate you were able to manage ? If not, why not ? And how would you fix the program to see the messages ?
 4. I suspect there is a constant relationship (divider) between THEJAS32 clock and the HEART BEAT signal. Can you find this ? Is this the same across boards ?
 5. What is the power consumption of only the THEJAS32 ? How does it relate to the clock speed ?

# One Last Thing!

If you don't connect GPIO30 to 3.3V, there is a good chance you won't see any messages on UART.  This is required due to an annoying design decision taken by whoever designed the bootloader of the THEJAS32 (and burnt it into ROM!).

The bootloader samples a whopping 7 GPIOs - GPIO31 to GPIO25.  Essentially, this is converted to a divider in the range 0 to 127.  The bootloader configures a UART baud rate equal to Sytem Clock/(16 x value). The ARIES boards pull up/down these GPIOs to set a baud rate of 115200.  Unfortunately, AtiVEGA doesn't.  So, if you don't connect a jumper, the divisor could become 0, effectively disabling UART messages. It can be really confusing when that happens. So, do populate the jumper.  With that, the bootloader will *mostly* set a baud rate of 195312.  There I said it, *mostly* !

Even with the jumper, on rare occasions, you won't see any messages coming from THEJAS32.  As the other GPIOs are "floating" rather than pulled down, there is a chance that THEJAS32 will sample one or more of them as high.  This will result in actual baud rate selected by THEJAS32 to be very different than what the RP2040 thinks it is.  Due to the baud rate mismatch, you won't see the messages.

Without spinning the board, hwo can this be handled ? Can you think of a scheme to automagically detect the baud rate of THEJAS32 from the RP2040 ? The good news is yes, you can. Look at the poweron_autobaud bringup sample for details.

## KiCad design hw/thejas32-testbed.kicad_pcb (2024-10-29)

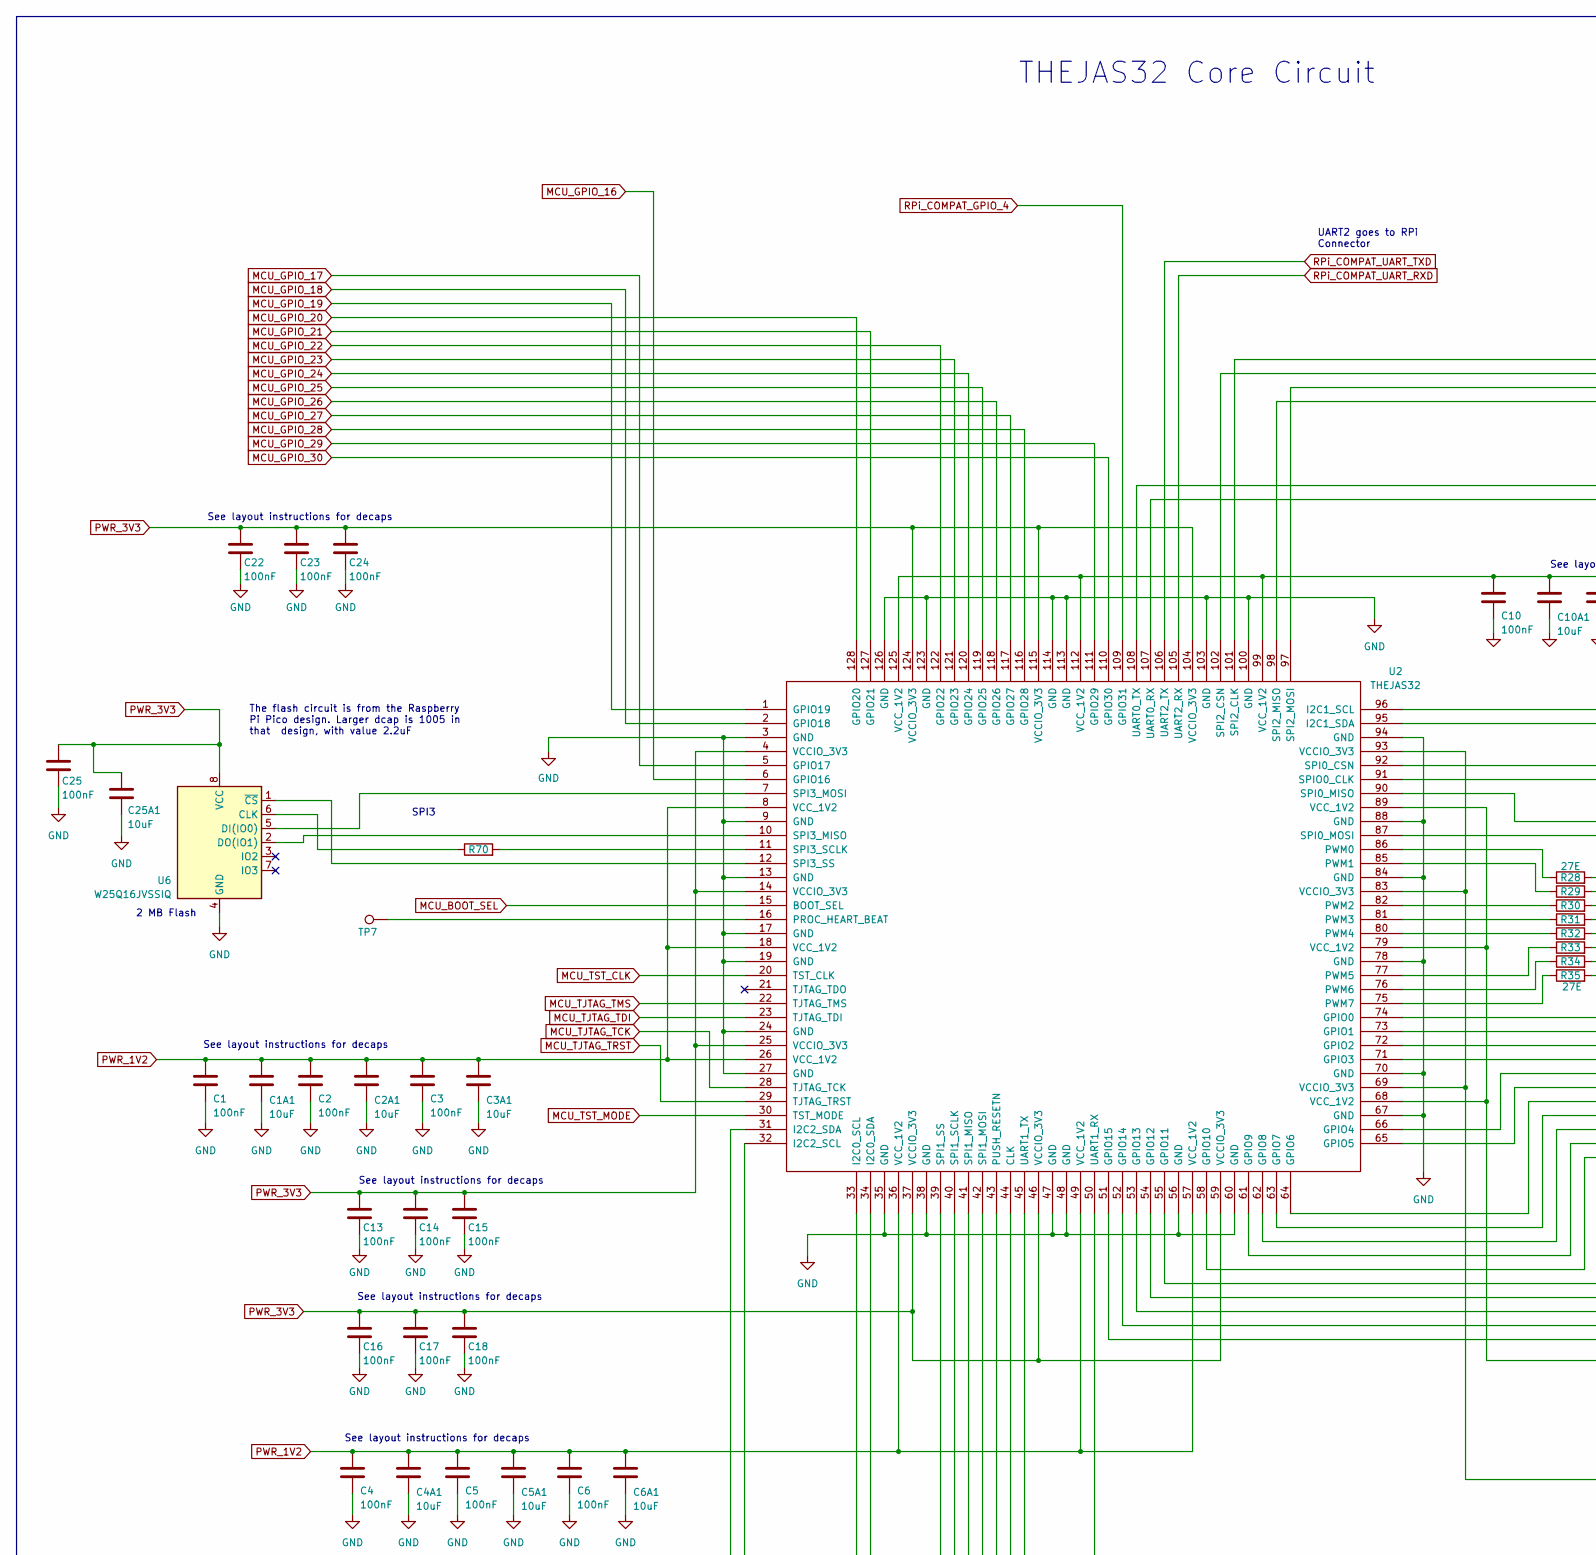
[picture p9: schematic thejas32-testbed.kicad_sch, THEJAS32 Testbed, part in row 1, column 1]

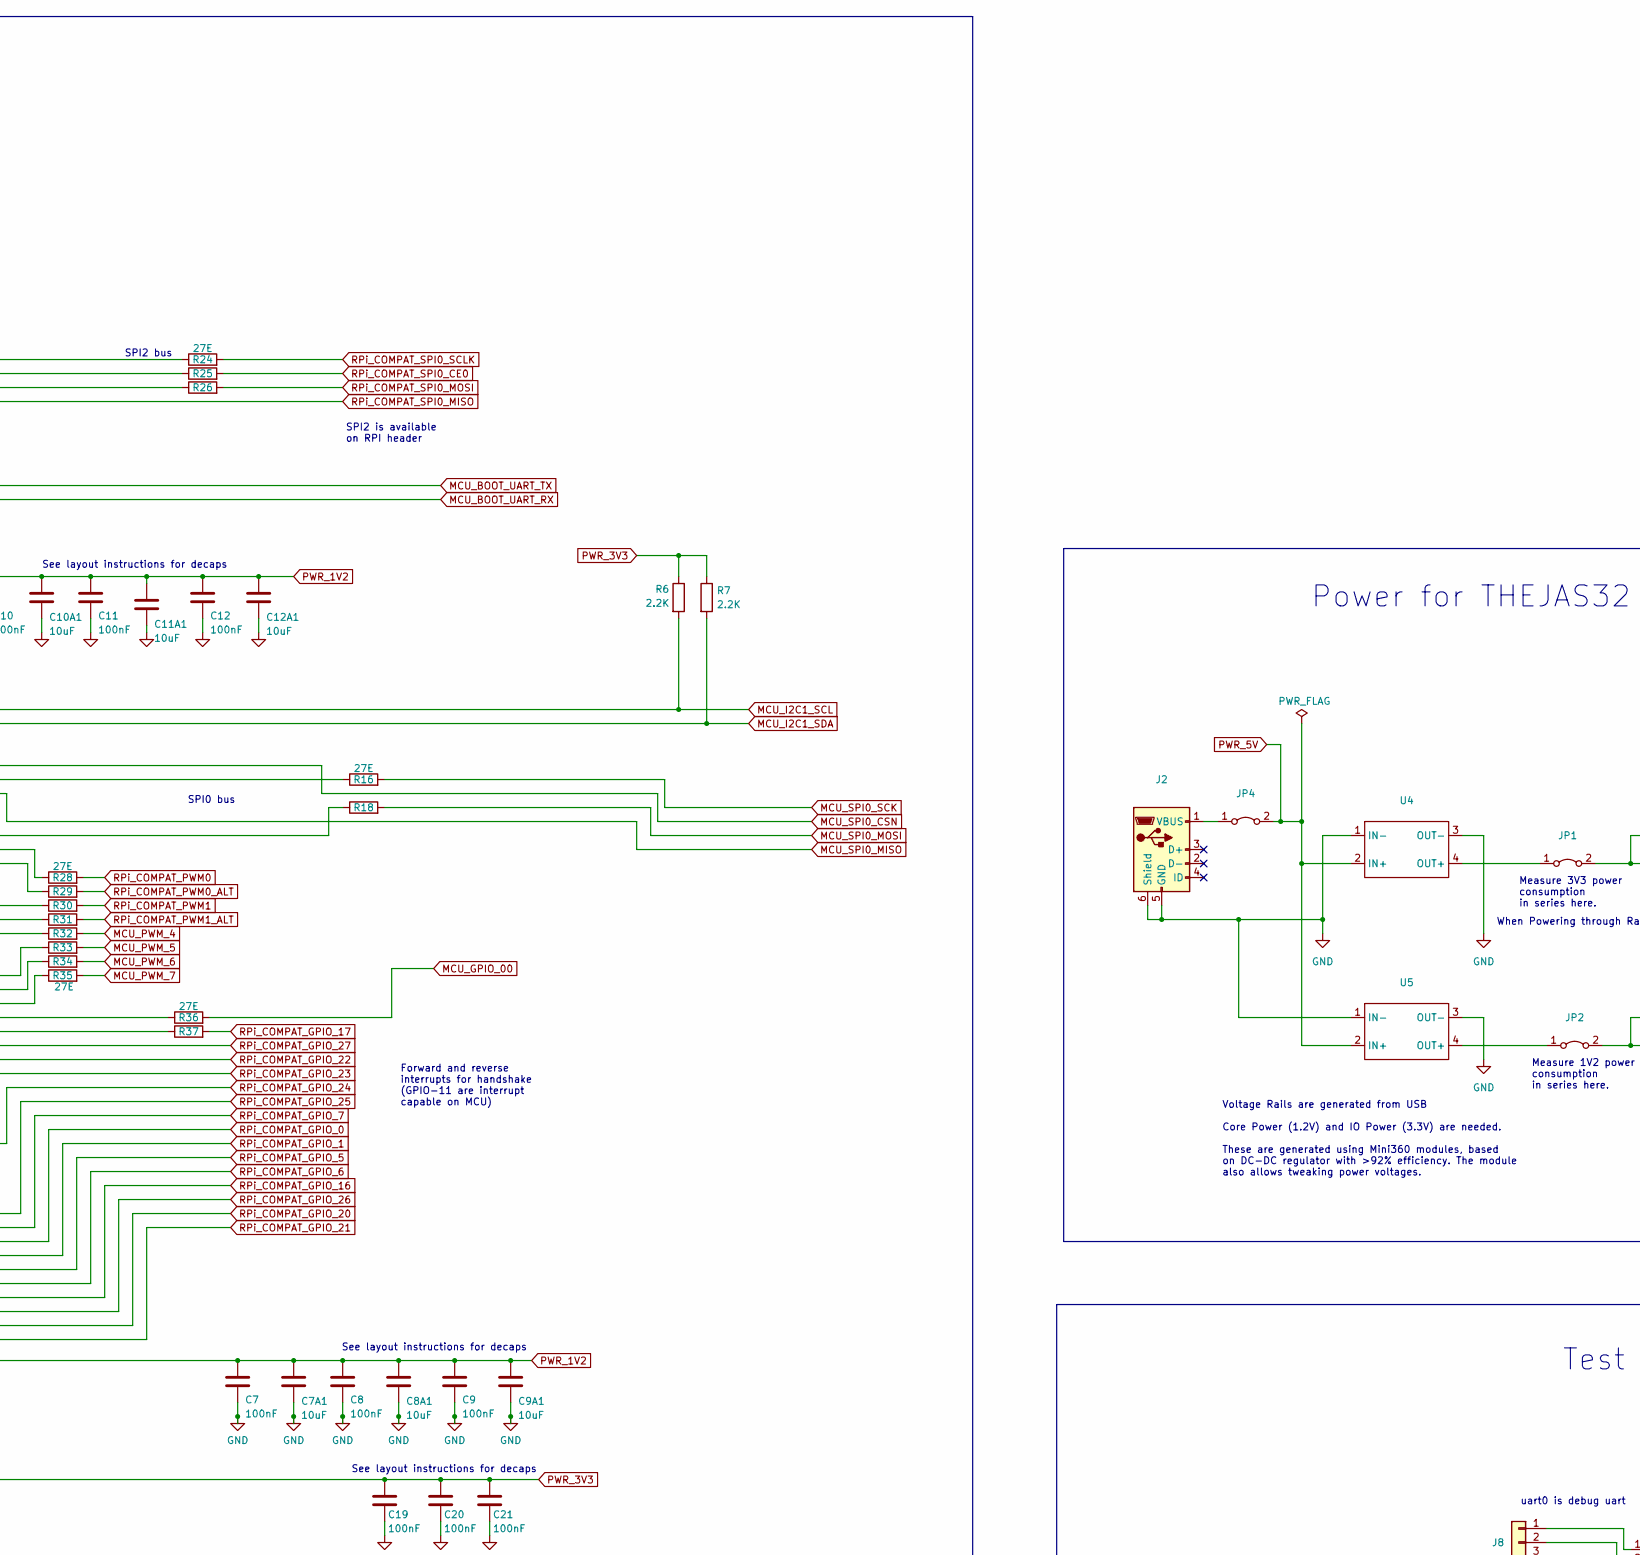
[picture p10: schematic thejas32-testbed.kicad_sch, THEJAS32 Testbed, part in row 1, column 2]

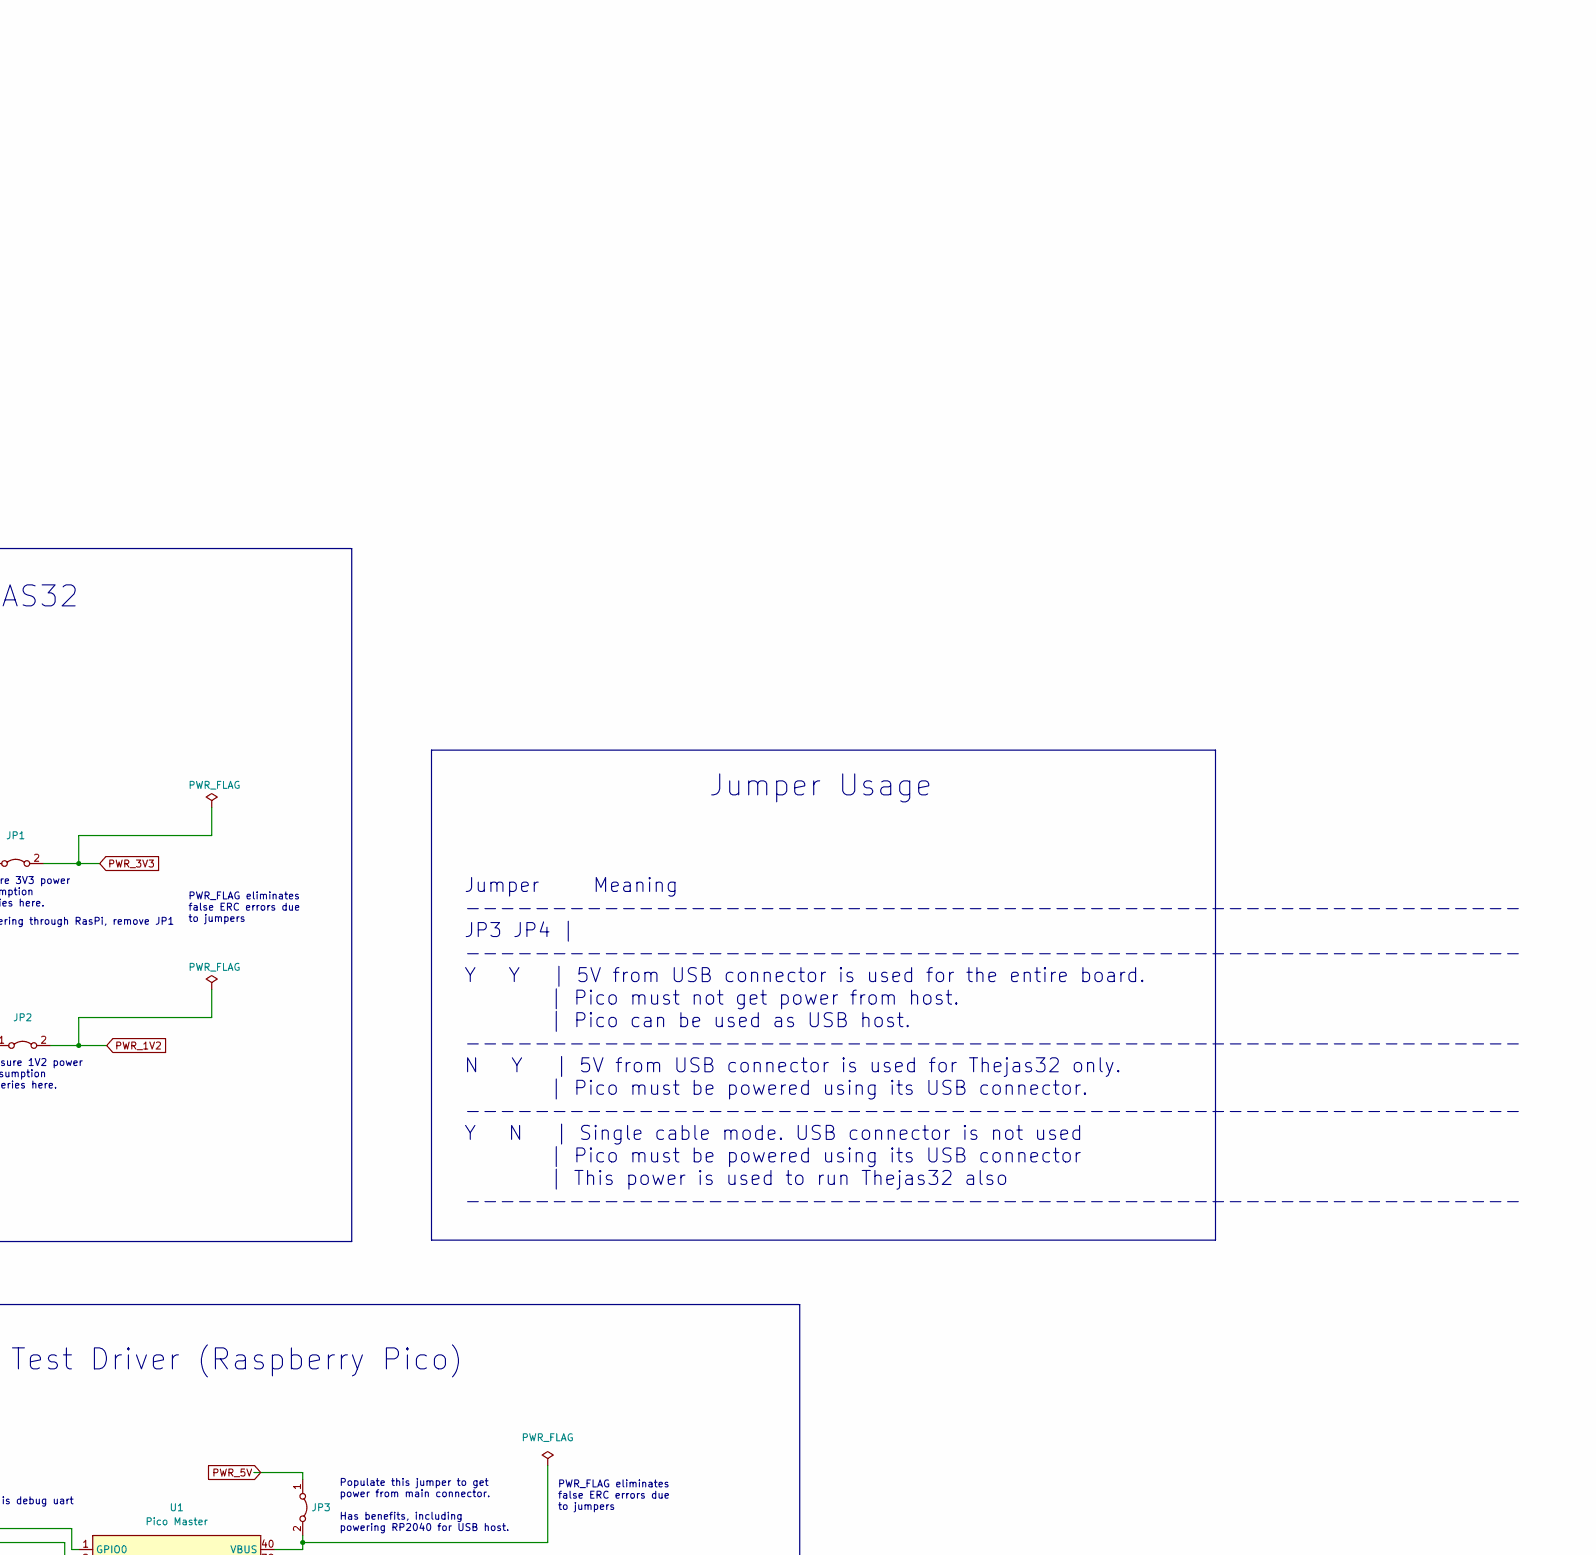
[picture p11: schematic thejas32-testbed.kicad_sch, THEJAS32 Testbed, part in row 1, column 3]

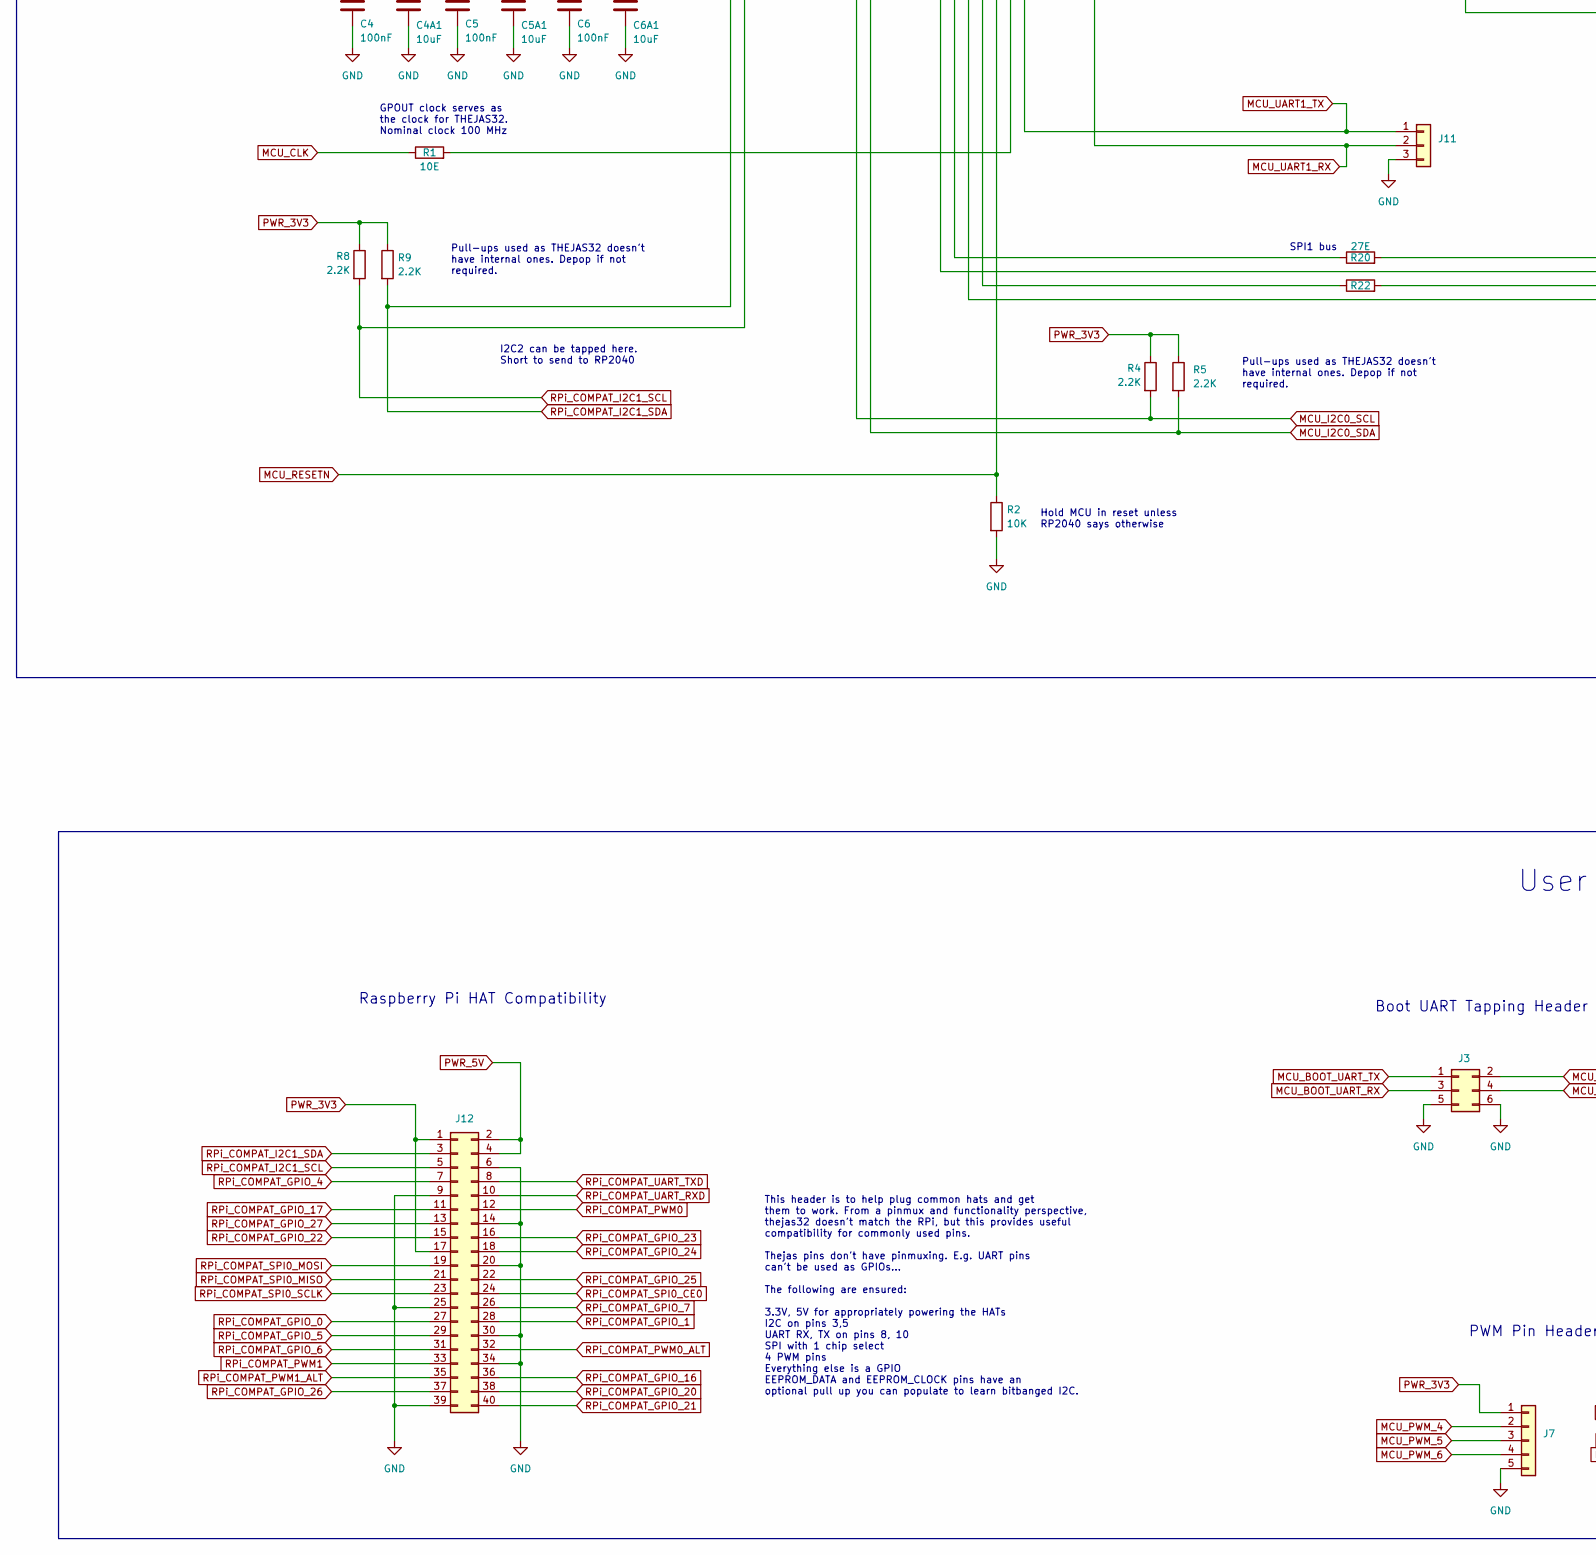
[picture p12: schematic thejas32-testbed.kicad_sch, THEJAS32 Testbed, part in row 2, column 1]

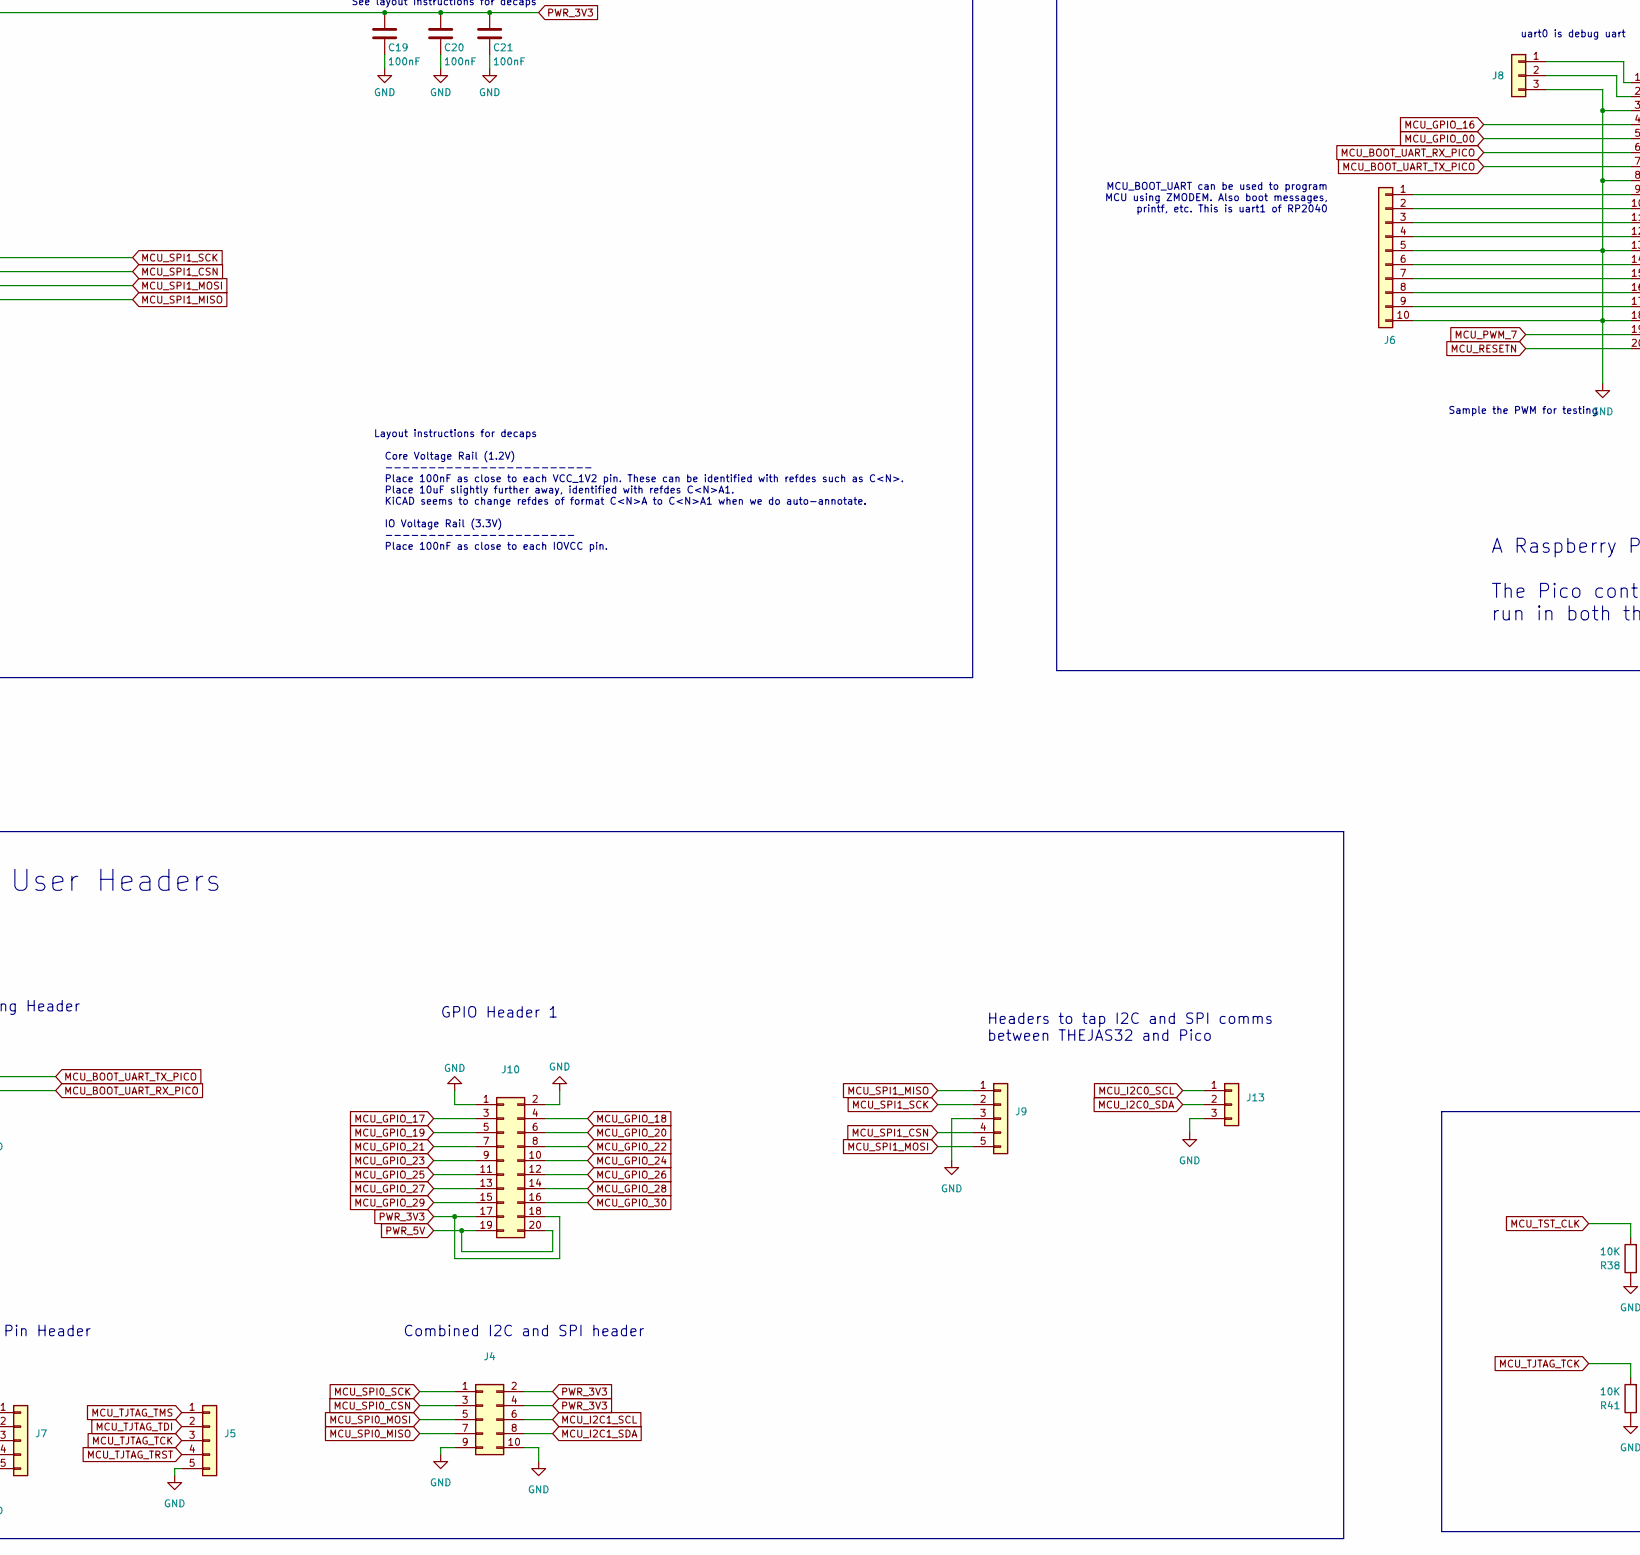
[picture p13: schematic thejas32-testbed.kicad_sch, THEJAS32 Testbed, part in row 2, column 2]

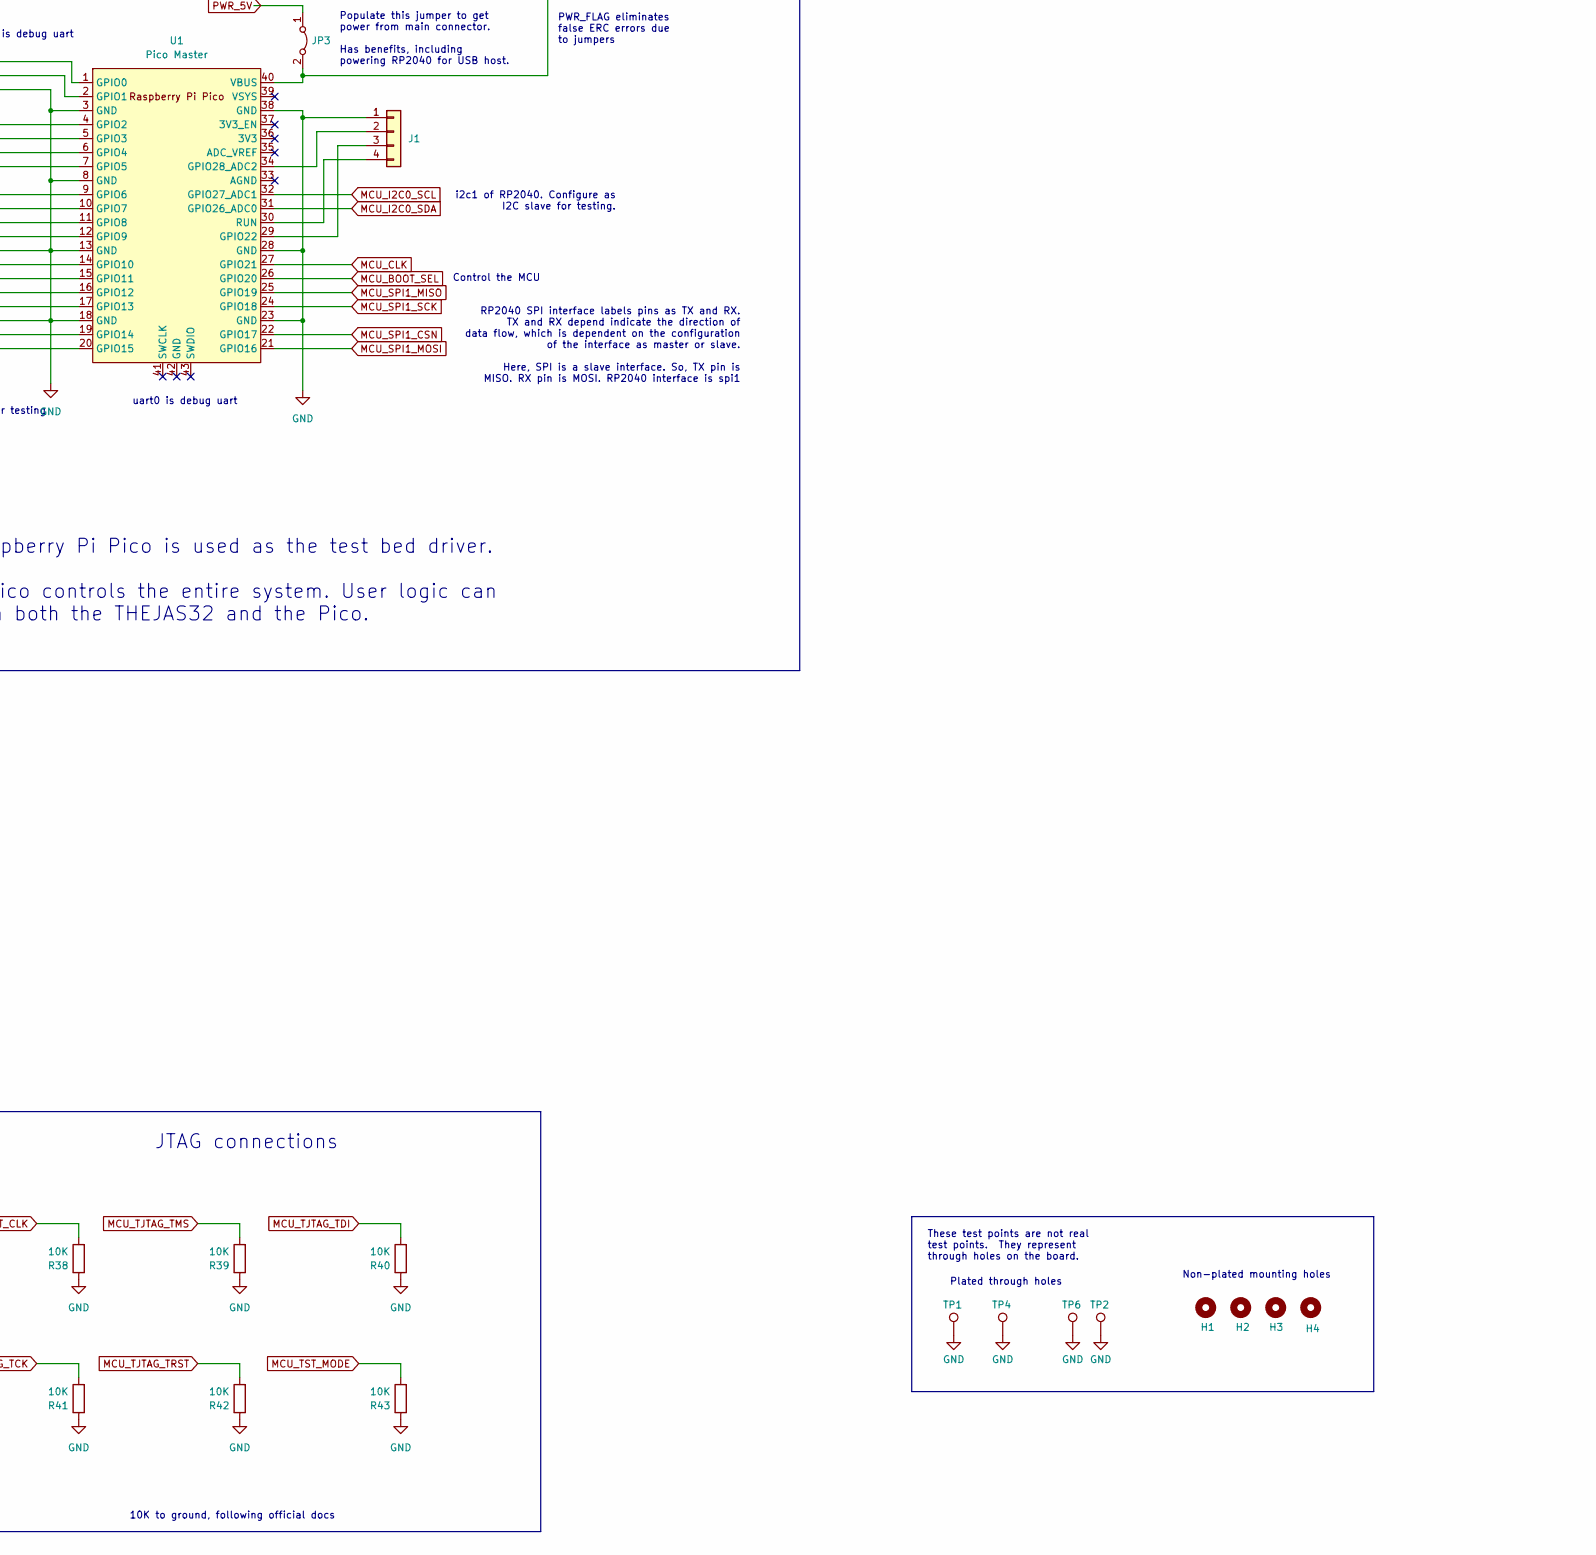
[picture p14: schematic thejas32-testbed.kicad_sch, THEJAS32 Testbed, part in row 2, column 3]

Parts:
C1, C2, C3, C4, C5, C6, C7, C8, C9, C10, C11, C12, C13, C14, C15, C16, C17, C18, C19, C20, C21, C22, C23, C24, C25: 100nF; proj_C_0603_1608Metric_Pad1.08x0.95mm_HandSolder; MPN 5190
C1A1, C2A1, C3A1, C4A1, C5A1, C6A1, C7A1, C8A1, C9A1, C10A1, C11A1, C12A1, C25A1: 10uF; proj_C_0603_1608Metric_Pad1.08x0.95mm_HandSolder; MPN 6799
H1, H2, H3, H4: MountingHole; MountingHole_3mm
J1: Conn_01x04; PinHeader_1x04_P2.54mm_Vertical; MPN 2.54 mm 1x4 pin male header
J2: USB_B_Micro; USB_Micro-B_Molex-105017-0001; MPN 4653
J3: Conn_02x03_Odd_Even; PinHeader_2x03_P2.54mm_Vertical; MPN 2.54 mm 2x3 pin male header
J4: Conn_02x05_Odd_Even; PinHeader_2x05_P2.54mm_Vertical; MPN 2.54 mm 2x5 pin male header
J5, J7, J9: Conn_01x05; PinHeader_1x05_P2.54mm_Vertical; MPN 2.54 mm 1x5 pin male header
J6: Conn_01x10; PinHeader_1x10_P2.54mm_Vertical; MPN 2.54 mm 1x10 pin male header
J8, J11, J13: Conn_01x03; PinHeader_1x03_P2.54mm_Vertical; MPN 2.54 mm 1x3 pin male header
J10: Conn_02x10_Odd_Even; PinHeader_2x10_P2.54mm_Vertical; MPN 2.54 mm 2x10 pin male header
J12: Conn_02x20_Odd_Even; PinHeader_2x20_P2.54mm_Vertical; MPN 2.54 mm 2x20 pin male header
JP1, JP2, JP3, JP4: Jumper_2_Bridged; PinHeader_1x02_P2.54mm_Vertical; MPN 2.54 mm 1x2 pin male header
R1, R70: 10E; proj_R_0603_1608Metric_Pad0.98x0.95mm_HandSolder; MPN 5354
R2, R38, R39, R40, R41, R42, R43: 10K; proj_R_0603_1608Metric_Pad0.98x0.95mm_HandSolder; MPN 5192
R4, R5, R6, R7, R8, R9: 2.2K; proj_R_0603_1608Metric_Pad0.98x0.95mm_HandSolder; MPN 6735
R16, R18, R20, R22, R24, R25, R26, R28, R29, R30, R31, R32, R33, R34, R35, R36, R37: 27E; proj_R_0603_1608Metric_Pad0.98x0.95mm_HandSolder; MPN 5297
TP1, TP2, TP4, TP6: Mounting Hole; MountingHole_3.2mm_M3_Pad_TopBottom
TP7: TestPoint; TestPoint_Pad_1.0x1.0mm
U1: Pico Master; RPi_Pico_SMD_TH; MPN Raspberry Pi Pico
U2: THEJAS32; LQFP-128_14x14mm_P0.4mm; MPN THEJAS32
U4, U5: Mini360_step-down; MPN 790469
U6: W25Q16JVSSIQ; SOIC-8_5.23x5.23mm_P1.27mm; MPN W25Q16JVSSIQ

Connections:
GND: C1.2, C1A1.2, C2.2, C2A1.2, C3.2, C3A1.2, C4.2, C4A1.2, C5.2, C5A1.2, C6.2, C6A1.2, C7.2, C7A1.2, C8.2, C8A1.2, C9.2, C9A1.2, C10.2, C10A1.2, C11.2, C11A1.2, C12.2, C12A1.2, C13.2, C14.2, C15.2, C16.2, C17.2, C18.2, C19.2, C20.2, C21.2, C22.2, C23.2, C24.2, C25.2, C25A1.2, J1.1, J2.5 (GND), J2.6 (Shield), J3.5, J3.6, J4.9, J4.10, J5.5, J6.5, J6.10, J7.5, J8.3, J9.3, J10.1, J10.2, J11.3, J12.6, J12.9, J12.14, J12.20, J12.25, J12.30, J12.34, J12.39, J13.3, R2.2, R38.1, R39.1, R40.1, R41.1, R42.1, R43.1, TP1.1, TP2.1, TP4.1, TP6.1, U1.3 (GND), U1.8 (GND), U1.13 (GND), U1.18 (GND), U1.23 (GND), U1.28 (GND), U1.38 (GND), U2.3 (GND), U2.9 (GND), U2.13 (GND), U2.17 (GND), U2.19 (GND), U2.24 (GND), U2.27 (GND), U2.35 (GND), U2.38 (GND), U2.47 (GND), U2.48 (GND), U2.56 (GND), U2.60 (GND), U2.67 (GND), U2.70 (GND), U2.78 (GND), U2.84 (GND), U2.88 (GND), U2.94 (GND), U2.100 (GND), U2.103 (GND), U2.113 (GND), U2.114 (GND), U2.123 (GND), U2.126 (GND), U4.1 (IN-), U4.3 (OUT-), U5.1 (IN-), U5.3 (OUT-), U6.4 (GND)
MCU_BOOT_SEL: U1.26 (GPIO20), U2.15 (BOOT_SEL)
MCU_BOOT_UART_RX: J3.3, U2.107 (UART0_RX)
MCU_BOOT_UART_RX_PICO: J3.4, U1.6 (GPIO4)
MCU_BOOT_UART_TX: J3.1, U2.108 (UART0_TX)
MCU_BOOT_UART_TX_PICO: J3.2, U1.7 (GPIO5)
MCU_CLK: R1.1, U1.27 (GPIO21)
MCU_GPIO_00: R36.2, U1.5 (GPIO3)
MCU_GPIO_16: U1.4 (GPIO2), U2.6 (GPIO16)
MCU_GPIO_17: J10.3, U2.5 (GPIO17)
MCU_GPIO_18: J10.4, U2.2 (GPIO18)
MCU_GPIO_19: J10.5, U2.1 (GPIO19)
MCU_GPIO_20: J10.6, U2.128 (GPIO20)
MCU_GPIO_21: J10.7, U2.127 (GPIO21)
MCU_GPIO_22: J10.8, U2.122 (GPIO22)
MCU_GPIO_23: J10.9, U2.121 (GPIO23)
MCU_GPIO_24: J10.10, U2.120 (GPIO24)
MCU_GPIO_25: J10.11, U2.119 (GPIO25)
MCU_GPIO_26: J10.12, U2.118 (GPIO26)
MCU_GPIO_27: J10.13, U2.117 (GPIO27)
MCU_GPIO_28: J10.14, U2.116 (GPIO28)
MCU_GPIO_29: J10.15, U2.111 (GPIO29)
MCU_GPIO_30: J10.16, U2.110 (GPIO30)
MCU_I2C0_SCL: J13.1, R4.2, U1.32 (GPIO27_ADC1), U2.33 (I2C0_SCL)
MCU_I2C0_SDA: J13.2, R5.2, U1.31 (GPIO26_ADC0), U2.34 (I2C0_SDA)
MCU_I2C1_SCL: J4.6, R6.2, U2.96 (I2C1_SCL)
MCU_I2C1_SDA: J4.8, R7.2, U2.95 (I2C1_SDA)
MCU_PWM_4: J7.2, R32.2
MCU_PWM_5: J7.3, R33.2
MCU_PWM_6: J7.4, R34.2
MCU_PWM_7: R35.2, U1.19 (GPIO14)
MCU_RESETN: R2.1, U1.20 (GPIO15), U2.43 (PUSH_RESETN)
MCU_SPI0_CSN: J4.3, U2.92 (SPI0_CSN)
MCU_SPI0_MISO: J4.7, U2.90 (SPI0_MISO)
MCU_SPI0_MOSI: J4.5, R18.2
MCU_SPI0_SCK: J4.1, R16.2
MCU_SPI1_CSN: J9.4, U1.22 (GPIO17), U2.39 (SPI1_SS)
MCU_SPI1_MISO: J9.1, U1.25 (GPIO19), U2.41 (SPI1_MISO)
MCU_SPI1_MOSI: J9.5, R22.2, U1.21 (GPIO16)
MCU_SPI1_SCK: J9.2, R20.2, U1.24 (GPIO18)
MCU_TJTAG_TCK: J5.3, R41.2, U2.28 (TJTAG_TCK)
MCU_TJTAG_TDI: J5.2, R40.2, U2.23 (TJTAG_TDI)
MCU_TJTAG_TMS: J5.1, R39.2, U2.22 (TJTAG_TMS)
MCU_TJTAG_TRST: J5.4, R42.2, U2.29 (TJTAG_TRST)
MCU_TST_CLK: R38.2, U2.20 (TST_CLK)
MCU_TST_MODE: R43.2, U2.30 (TST_MODE)
MCU_UART1_RX: J11.2, U2.50 (UART1_RX)
MCU_UART1_TX: J11.1, U2.45 (UART1_TX)
unnamed: J1.2, U1.34 (GPIO28_ADC2)
unnamed: J1.3, U1.29 (GPIO22)
unnamed: J1.4, U1.30 (RUN)
unnamed: J2.1 (VBUS), JP4.1 (A)
unnamed: J6.1, U1.9 (GPIO6)
unnamed: J6.2, U1.10 (GPIO7)
unnamed: J6.3, U1.11 (GPIO8)
unnamed: J6.4, U1.12 (GPIO9)
unnamed: J6.6, U1.14 (GPIO10)
unnamed: J6.7, U1.15 (GPIO11)
unnamed: J6.8, U1.16 (GPIO12)
unnamed: J6.9, U1.17 (GPIO13)
unnamed: J8.1, U1.1 (GPIO0)
unnamed: J8.2, U1.2 (GPIO1)
unnamed: JP1.1 (A), U4.4 (OUT+)
unnamed: JP2.1 (A), U5.4 (OUT+)
unnamed: JP3.2 (B), U1.40 (VBUS)
unnamed: R1.2, U2.44 (CLK)
unnamed: R36.1, U2.74 (GPIO0)
unnamed: R37.1, U2.73 (GPIO1)
unnamed: TP7.1, U2.16 (PROC_HEART_BEAT)
unnamed: R28.1, U2.86 (PWM0)
unnamed: R29.1, U2.85 (PWM1)
unnamed: R30.1, U2.82 (PWM2)
unnamed: R31.1, U2.81 (PWM3)
unnamed: R32.1, U2.80 (PWM4)
unnamed: R33.1, U2.77 (PWM5)
unnamed: R34.1, U2.76 (PWM6)
unnamed: R35.1, U2.75 (PWM7)
unnamed: R18.1, U2.87 (SPI0_MOSI)
unnamed: R22.1, U2.42 (SPI1_MOSI)
unnamed: R20.1, U2.40 (SPI1_SCLK)
unnamed: R24.1, U2.101 (SPI2_CLK)
unnamed: R25.1, U2.102 (SPI2_CSN)
unnamed: R26.1, U2.97 (SPI2_MOSI)
unnamed: U2.10 (SPI3_MISO), U6.2 (DO(IO1))
unnamed: U2.7 (SPI3_MOSI), U6.5 (DI(IO0))
unnamed: R70.2, U2.11 (SPI3_SCLK)
unnamed: U2.12 (SPI3_SS), U6.1 (~CS)
unnamed: R16.1, U2.91 (SPIO0_CLK)
unnamed: R70.1, U6.6 (CLK)
PWR_1V2: C1.1, C1A1.1, C2.1, C2A1.1, C3.1, C3A1.1, C4.1, C4A1.1, C5.1, C5A1.1, C6.1, C6A1.1, C7.1, C7A1.1, C8.1, C8A1.1, C9.1, C9A1.1, C10.1, C10A1.1, C11.1, C11A1.1, C12.1, C12A1.1, JP2.2 (B), U2.8 (VCC_1V2), U2.18 (VCC_1V2), U2.26 (VCC_1V2), U2.36 (VCC_1V2), U2.49 (VCC_1V2), U2.57 (VCC_1V2), U2.68 (VCC_1V2), U2.79 (VCC_1V2), U2.89 (VCC_1V2), U2.99 (VCC_1V2), U2.112 (VCC_1V2), U2.125 (VCC_1V2)
PWR_3V3: C13.1, C14.1, C15.1, C16.1, C17.1, C18.1, C19.1, C20.1, C21.1, C22.1, C23.1, C24.1, C25.1, C25A1.1, J4.2, J4.4, J7.1, J10.17, J10.18, J12.1, J12.17, JP1.2 (B), R4.1, R5.1, R6.1, R7.1, R8.1, R9.1, U2.4 (VCCIO_3V3), U2.14 (VCCIO_3V3), U2.25 (VCCIO_3V3), U2.37 (VCCIO_3V3), U2.46 (VCCIO_3V3), U2.59 (VCCIO_3V3), U2.69 (VCCIO_3V3), U2.83 (VCCIO_3V3), U2.93 (VCCIO_3V3), U2.104 (VCCIO_3V3), U2.115 (VCCIO_3V3), U2.124 (VCCIO_3V3), U6.8 (VCC)
PWR_5V: J10.19, J10.20, J12.2, J12.4, JP3.1 (A), JP4.2 (B), U4.2 (IN+), U5.2 (IN+)
RPi_COMPAT_GPIO_0: J12.27, U2.62 (GPIO8)
RPi_COMPAT_GPIO_1: J12.28, U2.61 (GPIO9)
RPi_COMPAT_GPIO_4: J12.7, U2.109 (GPIO31)
RPi_COMPAT_GPIO_5: J12.29, U2.58 (GPIO10)
RPi_COMPAT_GPIO_6: J12.31, U2.55 (GPIO11)
RPi_COMPAT_GPIO_7: J12.26, U2.63 (GPIO7)
RPi_COMPAT_GPIO_16: J12.36, U2.54 (GPIO12)
RPi_COMPAT_GPIO_17: J12.11, R37.2
RPi_COMPAT_GPIO_20: J12.38, U2.52 (GPIO14)
RPi_COMPAT_GPIO_21: J12.40, U2.51 (GPIO15)
RPi_COMPAT_GPIO_22: J12.15, U2.71 (GPIO3)
RPi_COMPAT_GPIO_23: J12.16, U2.66 (GPIO4)
RPi_COMPAT_GPIO_24: J12.18, U2.65 (GPIO5)
RPi_COMPAT_GPIO_25: J12.22, U2.64 (GPIO6)
RPi_COMPAT_GPIO_26: J12.37, U2.53 (GPIO13)
RPi_COMPAT_GPIO_27: J12.13, U2.72 (GPIO2)
RPi_COMPAT_I2C1_SCL: J12.5, R8.2, U2.32 (I2C2_SCL)
RPi_COMPAT_I2C1_SDA: J12.3, R9.2, U2.31 (I2C2_SDA)
RPi_COMPAT_PWM0: J12.12, R28.2
RPi_COMPAT_PWM0_ALT: J12.32, R29.2
RPi_COMPAT_PWM1: J12.33, R30.2
RPi_COMPAT_PWM1_ALT: J12.35, R31.2
RPi_COMPAT_SPI0_CE0: J12.24, R25.2
RPi_COMPAT_SPI0_MISO: J12.21, U2.98 (SPI2_MISO)
RPi_COMPAT_SPI0_MOSI: J12.19, R26.2
RPi_COMPAT_SPI0_SCLK: J12.23, R24.2
RPi_COMPAT_UART_RXD: J12.10, U2.105 (UART2_RX)
RPi_COMPAT_UART_TXD: J12.8, U2.106 (UART2_TX)

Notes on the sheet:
These test points are not real test points. They represent through holes on the board.
MCU_BOOT_UART can be used to program MCU using ZMODEM. Also boot messages, printf, etc. This is uart1 of RP2040
i2c1 of RP2040. Configure as I2C slave for testing.
uart0 is debug uart
See layout instructions for decaps
Raspberry Pi HAT Compatibility
Boot UART Tapping Header
THEJAS32 Core Circuit
UART2 goes to RPi Connector
Combined I2C and SPI header
Sample the PWM for testing
Forward and reverse interrupts for handshake (GPIO-11 are interrupt capable on MCU)
10K to ground, following official docs
Headers to tap I2C and SPI comms between THEJAS32 and Pico
When Powering through RasPi, remove JP1
SPI2 bus
I2C2 can be tapped here. Short to send to RP2040
This header is to help plug common hats and get them to work. From a pinmux and functionality perspective, thejas32 doesn't match the RPi, but this provides useful compatibility for commonly used pins. Thejas pins don't have pinmuxing. E.g. UART pins can't be used as GPIOs... The following are ensu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
Layout instructions for decaps Core Voltage Rail (1.2V) ------------------------ Place 100nF as close to each VCC_1V2 pin. These can be identified with refdes such as C<N>. Place 10uF slightly further away, identified with refdes C<N>A1. KiCAD seems to change refdes of format C<N>A to C<N>A1 when w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
Power for THEJAS32
Pull-ups used as THEJAS32 doesn't have internal ones. Depop if not required.
RP2040 SPI interface labels pins as TX and RX. TX and RX depend indicate the direction of data flow, which is dependent on the configuration of the interface as master or slave. Here, SPI is a slave interface. So, TX pin is MISO. RX pin is MOSI. RP2040 interface is spi1
JTAG connections
Hold MCU in reset unless RP2040 says otherwise
Populate this jumper to get power from main connector. Has benefits, including powering RP2040 for USB host.
Non-plated mounting holes
SPI1 bus
The flash circuit is from the Raspberry Pi Pico design. Larger dcap is 1005 in that design, with value 2.2uF
Measure 1V2 power consumption in series here.
PWM Pin Header
Voltage Rails are generated from USB Core Power (1.2V) and IO Power (3.3V) are needed. These are generated using Mini360 modules, based on DC-DC regulator with >92% efficiency. The module also allows tweaking power voltages.
Plated through holes
GPOUT clock serves as the clock for THEJAS32. Nominal clock 100 MHz
Jumper Meaning ------------------------------------------------------------- JP3 JP4 | ------------------------------------------------------------- Y Y | 5V from USB connector is used for the entire board. | Pico must not get power from host. | Pico can be used as USB host. -----------------------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
Test Driver (Raspberry Pico)
PWR_FLAG eliminates false ERC errors due to jumpers
SPI2 is available on RPI header
User Headers
GPIO Header 1
Jumper Usage

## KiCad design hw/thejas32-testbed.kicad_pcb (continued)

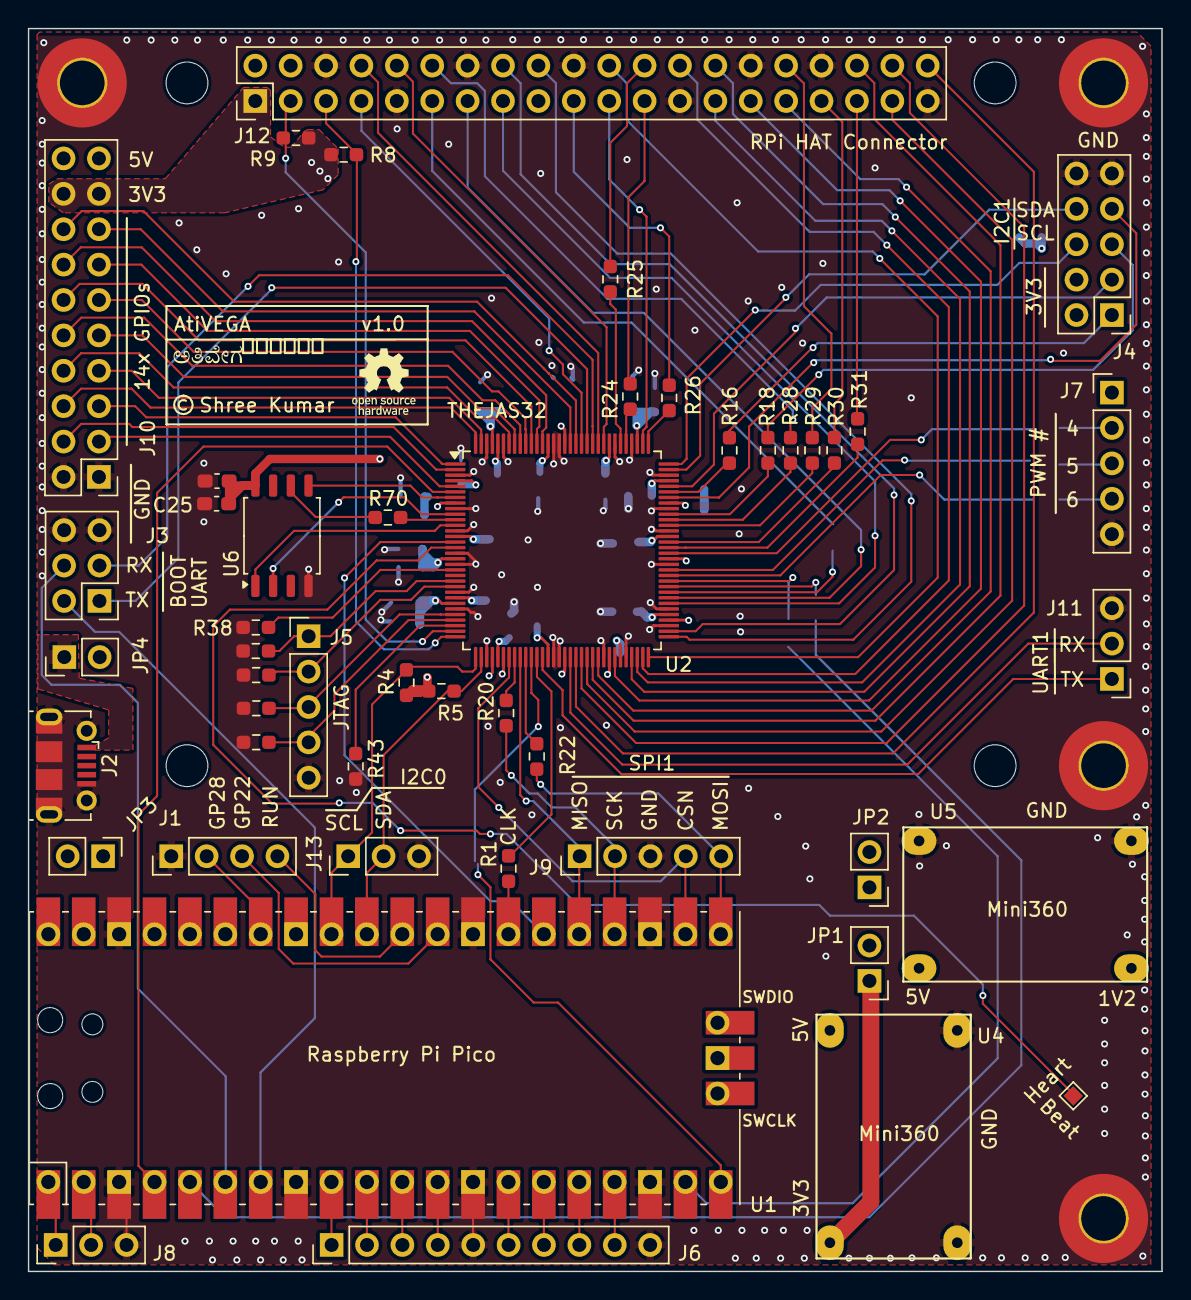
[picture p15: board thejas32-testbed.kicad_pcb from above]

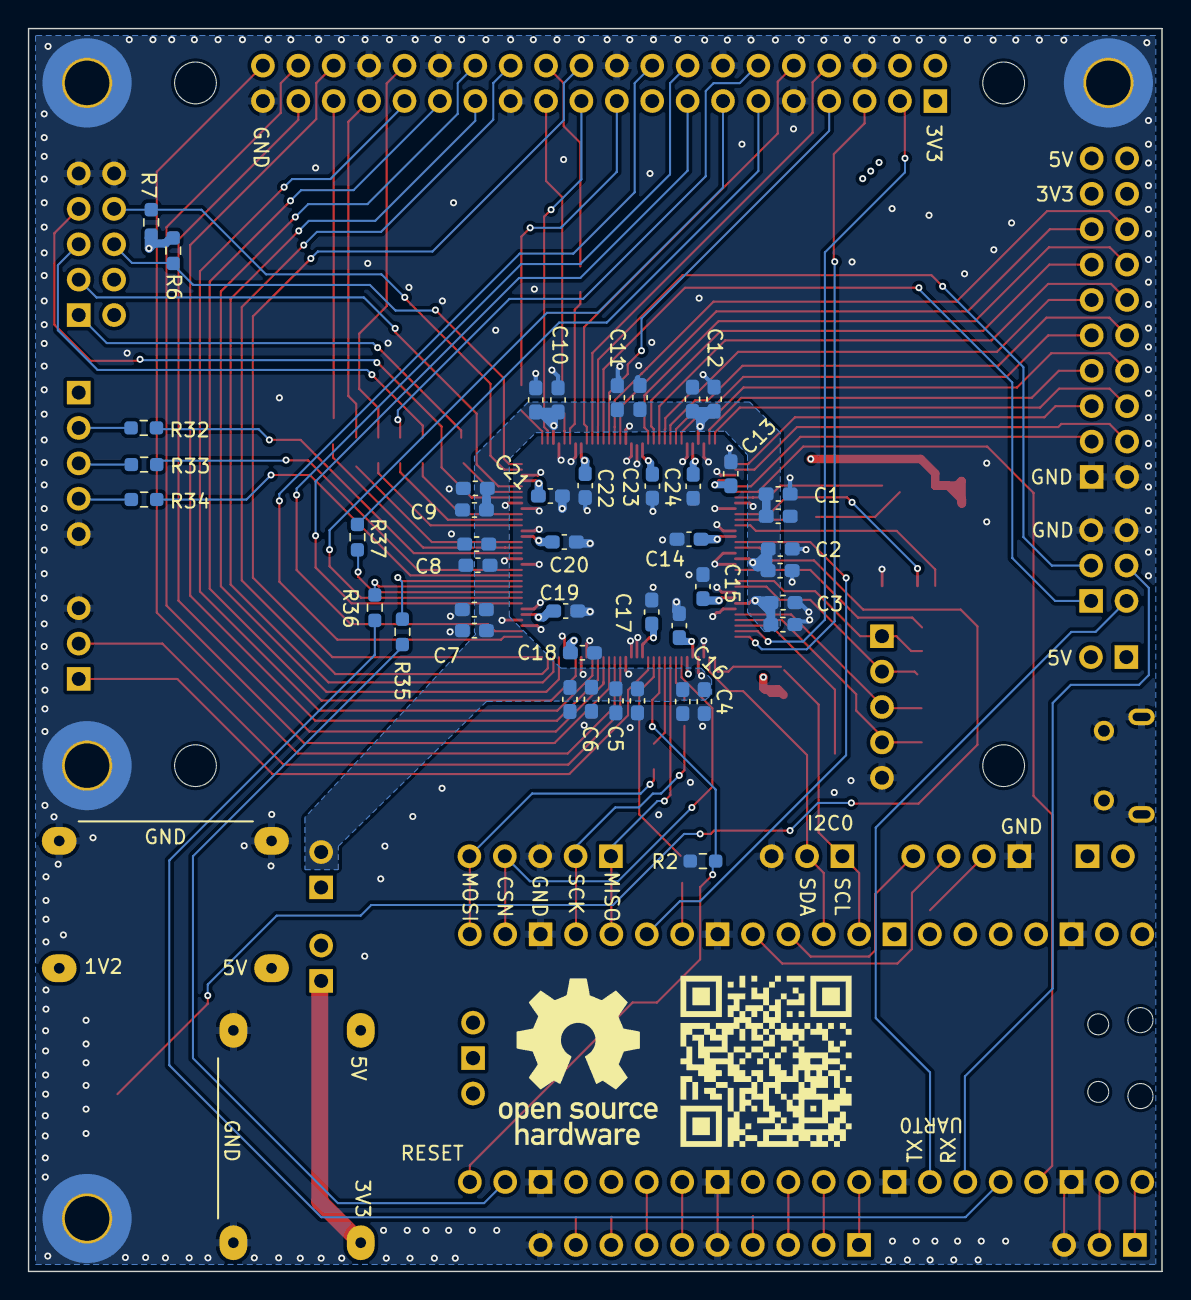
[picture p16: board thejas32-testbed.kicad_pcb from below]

Board: 4 copper layers, 81.4 x 89.2 mm, 101 parts (45 on the bottom side), 120 nets.

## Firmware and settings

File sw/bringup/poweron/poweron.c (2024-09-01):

// 
// First boot of AtiVEGA board, with THEJAS32
// enabled
//
// Basically powers on the chip and dumps the UART log
//
#include <stdio.h>
#include "pico/stdlib.h"
#include "hardware/clocks.h"

const uint8_t PICO_LED = 25;

// T_ prefix for pins connected to THEJAS32 from Pico
const uint8_t T_RESETN_PIN = 15;
const uint8_t T_CLK_PIN = 21;
const uint8_t T_BOOTSEL_PIN = 20;
const uint8_t T_BOOT_UART_RX_PIN = 4;
const uint8_t T_BOOT_UART_TX_PIN = 5;

const uint8_t BOOT_MODE_UART = 1;
#define BOOT_UART_ID uart1

// THEJAS32 clock frequency = System Clock/T_CLK_DIV
// Basically slows down THEJAS32 clock by this factor,
// relative to system clock (100 MHz)
const int T_CLK_DIV = 1;

uint8_t led_state = 1;

int main()
{
    // System clock is already running at 100 MHz at this point
    // See CMakeLists.txt for configuration

    // Turn on the Pico LED - this is the only LED on the entire board!
    gpio_init(PICO_LED);
    gpio_set_dir(PICO_LED, GPIO_OUT);
    gpio_put(PICO_LED, led_state);

    // Wait for CDC initialization - refer CMakeLists.txt for maximum
    // wait time.
    stdio_init_all();
    printf("\n=========================================================\n");
    printf("AtiVEGA ready to power-on THEJAS32\n");

    // Keep THEJAS32 in reset. The board has a pull down resistor,
    // so strictly speaking this is not required at this time.
    gpio_init(T_RESETN_PIN);
    gpio_set_dir(T_RESETN_PIN, GPIO_OUT);
    gpio_put(T_RESETN_PIN, 0);
   
    // THEJAS32 can boot in "default" mode - throught UART, or
    // by loading code in flash over SPI. This is set via
    // the BOOT_MODE pin - connected to a Pico GPIO pin.
    //
    // Here we choose to boot over UART.  THEJAS has a bootrom
    // that implements XMODEM protocol (with CRC) over UART.
    // After uploading, programs can be run from RAM. This sample
    // won't do that, though!
    gpio_init(T_BOOTSEL_PIN);
    gpio_set_dir(T_BOOTSEL_PIN, GPIO_OUT);
    gpio_put(T_BOOTSEL_PIN, BOOT_MODE_UART);

    // Once THEJAS32 powers on, it will start putting out messages on UART.
    // So we setup UART to capture these messages in advance.
    //
    // We use (strange value?) 195312 baud!  This corresponds to GPIO setting.
    //
    // For this program to work, you need to set GPIO 30 to high.
    // Use a jumper between GPIO30 and the adjacent 3.3V pin.
    // The rest of the GPIOs below will be "floating" state,
    // but mostly they can be considered as 0.
    //
    // GPIO 31 30 29 28 27 26 25
    //       0  1  0  0  0  0  0 => 32 (decimal)
    //
    // THEJAS32 boot loader looks at these GPIOs and
    // sets up the UART baud rate registers
    // = system clock/(16*value)
    // = 100*1e6/(16*32)
    // = 195312.5
    // If T_CLK_DIV is >1, then baud rate of communication will be lower
    // Take care to ensure even division if you can, else what may happen?
    uint sys_clk_rate = clock_get_hz(clk_sys);
    uint baud = (sys_clk_rate/T_CLK_DIV)/(16*32);
    uint baud_achieved = uart_init(BOOT_UART_ID, baud);
    printf("Communicating with THEJAS32 at UART baud=%d\n",baud_achieved);
    printf("                              (requested:%d)\n",baud);
    gpio_set_function(T_BOOT_UART_TX_PIN, UART_FUNCSEL_NUM(BOOT_UART_ID, T_BOOT_UART_TX_PIN));
    gpio_set_function(T_BOOT_UART_RX_PIN, UART_FUNCSEL_NUM(BOOT_UART_ID, T_BOOT_UART_RX_PIN));

    uint thejas_clk_rate = sys_clk_rate/T_CLK_DIV;
    printf("Powering on with clock=%d Hz _after_ 3 seconds!\n",thejas_clk_rate);
    printf("THEJAS32's boot log will follow after the next line\n");
    printf("=========================================================\n");
    // wait for all the prints to finish - USB can take some time! This is here to avoid
    // any trouble with the USB stack, just in case you decide to eliminate the sleeps
    // below and try doing timing.
    uart_default_tx_wait_blocking();

    // build some suspense - 3...2...1... go!
    for(int i=3;i>=0;i--) {
        if(i>0) {
            printf("\r%d...",i);
            sleep_ms(1000);
        } else {
            // erase previous prints
            printf("\r    \r");
        }
        uart_default_tx_wait_blocking();
    }

    // Now, start THEJAS32 clock at 100/CLK_DIV MHz
    clock_gpio_init(T_CLK_PIN, CLOCKS_CLK_GPOUT0_CTRL_AUXSRC_VALUE_CLK_SYS, T_CLK_DIV);

    // Show-time ! Get THEJAS32 out of reset
    gpio_put(T_RESETN_PIN, 1);

    absolute_time_t t_start = get_absolute_time();
    absolute_time_t t_first_ch;
    int prev_ch = -1;
    int prev2_ch = -1;
    bool ready = false;
    // Dump everything that comes on UART to USB
    while(1) {
        if(uart_is_readable(BOOT_UART_ID)) {
            if(prev_ch==-1) {
                t_first_ch = get_absolute_time();
            }

            int ch = uart_getc(BOOT_UART_ID);
            // In UART boot mode, THEJAS32 uses the XMODEM with CRC as the
            // protocol to upload software. Those 'C' characters indicate
            // that THEJAS32 is ready to receive a software image to boot.
            // We need to track the first of these, but we need to ignore
            // occurences of 'C' that happen in the header. The 'C' indicating
            // "send image" is preceded by a space and a newline. That's
            // how we differentiate
            if((!ready) &&
                   (ch=='C') && (prev2_ch==13) && (prev_ch==32)) {
                    absolute_time_t t_ready = get_absolute_time();
                printf(
                    "\n\n==> Ready to receive image %lld microseconds after power on.\n",
                     absolute_time_diff_us(t_start, t_ready));
                printf("==> First char was received %lld microseconds after power on.\n\n",
                     absolute_time_diff_us(t_start, t_first_ch));
                ready = true;
            }

            // dump the data from THEJAS32 to USB
            printf("%c",ch);

            // Toggle LED
            led_state ^= 1;
            gpio_put(PICO_LED, led_state);

            prev2_ch = prev_ch;
            prev_ch = ch;
        }
    }

    return 0;
}

// Exercises for reader
//
// 1. What is the _lowest_ frequency at which this program can
//    clock THEJAS32 ? Will everything work reliably ?
// 2. How can you overclock THEJAS32 beyond 100 MHz ? What happens?

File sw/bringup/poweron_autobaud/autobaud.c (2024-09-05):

#include <stdio.h>
#include "pico/stdlib.h"
#include "measure.pio.h"
#include "autobaud.h"

#define BOOT_DELAY 80 // millisecond reference for 100 MHz
#define BASE_CLK_RATE 100*1000*1000LL
#define C_DELAY_MIN 0.1f // min wait in "CCCCC" state of XMODEM protocol
#define C_DELAY_MAX 0.25f // max wait in "CCCCC" state of XMODEM protocol
static PIO pio = pio0;
static uint offset;
static uint sm;

void autobaud_init(uint8_t rx_pin, uint T_CLK_DIV)
{
    offset = pio_add_program(pio, &measure_program);
    sm = pio_claim_unused_sm(pio, true);
    measure_program_init(pio, sm, offset, rx_pin, T_CLK_DIV);
}

static bool get_bit_span(uint* count, int T_CLK_DIV)
{
    *count = 0;
    absolute_time_t t_start = get_absolute_time();
    absolute_time_t t_wait_end = delayed_by_ms(t_start, 2000*T_CLK_DIV);
    while(pio_sm_is_rx_fifo_empty(pio,sm)) {
	    absolute_time_t t_cur = get_absolute_time();
	    if(absolute_time_diff_us(t_cur, t_wait_end)<0) {
		printf("Timeout %lld %lld %lld\n", t_cur, t_wait_end, t_start);
		return false;
            }
    }

    uint bs;
    // process high to low
    bs = pio_sm_get_blocking(pio, sm);
    bs = 0xffffffff - bs;
    bs = bs*2; // inner loop is two instructions
    bs++; // and the mov null
    *count = bs;
    return true;
}

int autodetect_baud_rate(uint sys_clk_rate, int T_CLK_DIV)
{
    uint measured_baud = 0;
    //uart_deinit(T_BOOT_UART_ID);
    pio_sm_set_enabled(pio, sm, false); // stop program
    pio_sm_set_enabled(pio, sm, true); // start program

    uint total_delay = (((BOOT_DELAY*T_CLK_DIV*(BASE_CLK_RATE/1000))/(sys_clk_rate/1000))/1000)+1;
    printf("Waiting for initial phase - %d sec...\n",total_delay);
    // give time for the initial CDAC prints phase to pass
    for(uint i=0;i<total_delay;i++) {
        sleep_ms(1000);
	printf("%4d\r",i);
    }

    printf("\nMeasuring baud rate...\n");

    uint count;
    if(!get_bit_span(&count, T_CLK_DIV)) {
      printf("Baud rate detect failed - 1\n");
      return 0;
    }
    //printf("State length %u\n",count); // debug print

    uint delay_min = sys_clk_rate*C_DELAY_MIN;
    uint delay_max = sys_clk_rate*C_DELAY_MAX;
    while(1) {
            // count is in units of system clock cycles, roughly
            if(!get_bit_span(&count, T_CLK_DIV)) {
              printf("Baud rate detect failed - 2\n");
              return 0;
	    }
	    //printf("clk=%u State length %u, range=%u to %lu\n", sys_clk_rate, count, delay_min, delay_max); // debug print
	    if((count>delay_min)&&(count<delay_max)) { // pulse 150<ms<200?
	        // next is stop bit
                if(!get_bit_span(&count, T_CLK_DIV)) {
                  printf("Baud rate detect failed - 3\n");
                  return 0;
	        }
		// count corresponds to length of stop bit
		measured_baud = sys_clk_rate/(count*T_CLK_DIV);
		break;
	    }
	    // this 
    }
    pio_sm_set_enabled(pio, sm, false); // stop program
    printf("Measured baud rate=%d\n", measured_baud);
/*
    uint baud_achieved = uart_init(T_BOOT_UART_ID, measured_baud);
    printf("Achieved baud rate=%d\n", baud_achieved);

    gpio_set_function(T_BOOT_UART_TX_PIN, UART_FUNCSEL_NUM(T_BOOT_UART_ID, T_BOOT_UART_TX_PIN));
    gpio_set_function(T_BOOT_UART_RX_PIN, UART_FUNCSEL_NUM(T_BOOT_UART_ID, T_BOOT_UART_RX_PIN));
*/
    return measured_baud;
}

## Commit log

2024-03-08 Base design, prep for review
    [thejas32-testbed.kicad_pcb, thejas32-testbed.kicad_sch]
2024-03-08 Add PTH on board edges
    [thejas32-testbed.kicad_pcb, thejas32-testbed.kicad_sch]
2024-03-08 Board stackup from Atharava's board
    [thejas32-testbed.kicad_pcb]
2024-03-09 Add footprint for Mini360
    Roughly tested using calipers against a physical module.
    Source of footprint:
    https://github.com/rayvburn/KiCad/tree/master/Mini360_step_down_converter/Mini360_step-down.pretty
    Commit 69583e8
    [thejas32-testbed.kicad_pcb, thejas32-testbed.kicad_sch]
2024-03-16 Various simplifications, initial routing.
    This is a commit for review.
    Schematic is modified to remove many zero ohms. RPi
    connector brought in.
    Layout shows 3V3 and 1V2 power planes. Pin mapping
    may need to change to avoid usage of layer 3 for
    signals if possible.
    [thejas32-testbed.kicad_pcb, thejas32-testbed.kicad_sch]
2024-03-20 Review,power shapes,dcap placement from Atharva
    All dcaps are now at layer 4, leaving lot
    more space on layer 1 for signal breakout.
    Flow of 1V2 power is deemed good - power plane,
    flowing to caps, through via to pins. Flow of 3V3
    power is reasonable - power plane with vias to both
    caps and pins.
    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
    [thejas32-testbed.kicad_pcb, thejas32-testbed.kicad_sch]
2024-03-21 Remap pins for less criss cross. Get rid of tracks
    Got rid of tracks to start tracks afresh once placement is
    done.
    [thejas32-testbed.kicad_pcb, thejas32-testbed.kicad_sch]
2024-03-21 Reduce criss cross further with mapping changes
    [thejas32-testbed.kicad_sch]
2024-03-21 Point KiCad-RP-Pico to fork.
2024-03-22 Potentially cleaner routing
    Main changes:
    - No more than 1 via on high speed trace (e.g. SPI)
    - Use two vias on slower GPIOs to maintain topology
    - Use via on the thick 5V trace supplying power to
    RPi connector
    [thejas32-testbed.kicad_pcb]
2024-03-22 Minor schematic changes
    Mounting holes are M3 pads.
    PWM pin routed to Pico is excluded from header
    Position of connectors improved.
    [thejas32-testbed.kicad_sch]
2024-03-22 Nicely routed PCB, clean lines
    Reasonable spacing between traces. Could be improved.
    Done for testing mostly.
    [thejas32-testbed.kicad_pcb]
2024-04-04 Single pico, new layout
    Figured two picos was too much as a concept. So, simplify.
    Reduce number of jumpers etc also (especially in passthrough).
    The single pico breaks out pins conveniently for users for
    usage.
    [thejas32-testbed.kicad_pcb, thejas32-testbed.kicad_sch]
2024-06-17 Incorporated most review comments.
    Used 5 mils traces in breakout area. This results in very few DRC
    errors iff track spacing is set to 5 mils. However, setting it to
    8 mils (in board settings) does complain essentially for every pad
    of the THEJAS32. Those just need to be waived off.
    Ensure 16 mils track separation, except in breakout area. This can
    be verified by setting the track spacing to 16 mils and running the
    DRC. Except for the core area, and some issues on the USB connector,
    no other errors must pop up.
    Poured copper on every layer. Added GND vias to increase GND pour.
    Moved flash IC to improve routing to the GPIO connector.
    Moved USB connector close to the RP2040s USB connecto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
    [thejas32-testbed.kicad_pcb, thejas32-testbed.kicad_sch]
2024-06-17 Heartbeat moved near mini360s
    Also corrected the file path of the 3D model for the
    flash IC
    [thejas32-testbed.kicad_pcb]
2024-06-18 Cleanup and beautification for review.
    Added silkscreen for all components.
    Grouped schematic for reading clarity.
    No circuit level changes, few nets renamed.
    [thejas32-testbed.kicad_pcb, thejas32-testbed.kicad_sch]
2024-06-18 Ready for review, all comments included
    All MPNs are provided
    Silkscreen updated
    BOM generation corrected.
    [thejas32-testbed.kicad_pcb, thejas32-testbed.kicad_sch]
2024-07-24 Updates from review
    Some major changes:
    1. JTAG connector
    2. Cleaned up layout in breakout area
    3. Improved MCU_CLOCK routing
    4. Alignment on right side jumpers
    5. 5V included in J10
    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
    [thejas32-testbed.kicad_pcb, thejas32-testbed.kicad_sch]
2024-07-24 Align Pico USB connector to board edge
    Also moved J8, J6 and J9 to the left to match the Pico.
    [thejas32-testbed.kicad_pcb]
2024-07-24 Doc updates
    [thejas32-testbed.kicad_sch]
2024-08-06 USB footprint changed to Molex-105017-0001
    This component is very close to Sunrom Part 4653
    https://www.sunrom.com/p/microusb-connector-with-through-hole-support-legs
    I am using the footprint from Molex, but the board
    will use the Sunrom part.
    [thejas32-testbed.kicad_pcb, thejas32-testbed.kicad_sch]
2024-08-06 Fix component properties
    Added manufacturer, corrected MPN and description
    These aren't provided for berg connectors
    [thejas32-testbed.kicad_sch]
2024-08-06 Fix silkscreen for GPIO pin
    [thejas32-testbed.kicad_pcb]
2024-08-06 3d model of MicroUSB connector
    [1050170001.stp, thejas32-testbed.kicad_pcb]
2024-08-06 Nice PCB top view from KiCAD render
2024-08-08 Address review comments from Atharva
    Various changes:
    1. Deleted GND via near R9
    2. Added vias near corner mounting holes
    3. Thermal spoke width 40 mils for PWR_5V
    on 3rd layer
    4. Fix square trace near J10.19
    5. GND shapes on all planes - change to
    relief for PTH. Spoke width 20 mils
    6. U1.26 routed trace above through-hole
    pafs
    7. Improved routing of MCU_RESETN and
    HEARTBEAT for better GND shapes
    8. U1.1-3 adjust traces to leave pad at
    90 degree
    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
    [thejas32-testbed.kicad_pcb]
2024-08-08 Update board render with silkscreen
2024-08-11 PCB and Silkscreen improvements
    Added a couple of vias to create grounds between
    traces. Moved a couple of traces to improve ground
    near Pico.
    Added github link as QR code on bottom silk
    [thejas32-testbed.kicad_pcb]
2024-08-11 Aligned with JLCPCB
    0 DRC errors, 4 warnings.
    Impedance matching on board - selected layer stackup on JLCPCB
    is JLC04161H-3313. So, 6 mil traces have 50 ohm impedance.
    Changed all 8 mil traces to 6 mils now. There are no "breakout"
    traces - as everything is normalized to 6 mils. Existing 5 and
    5.5 mil traces also promoted to 6 mils.
    Board constraints are set to minimum clearance 5 mils, trace
    width 6 mils. If you set minimum clearance to 6 mils, you'll see
    DRC error on almost all THEJAS32 pads, complaining of "actual
    clearance 5.92 mils, expected 6 mils". KiCAD doesn't seem to
    honour fractional values, so I have to set it to 5 mils to pass.
    Misc other changes:
    1. USB connector is set up a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
    [thejas32-testbed.kicad_pcb]
2024-08-12 Cleanup
    Cleaned up a few 8 mils signal tracks
    Used Tools | Cleanup Tracks & Vias... This cleans
    up tracks in pads, merges linear tracks, etc.
    Aligned JTAG resistors in a line.
    [thejas32-testbed.kicad_pcb]
2024-08-12 PCB top view image on black background
2024-08-12 Fixed 7 mils GND and PWR traces near THEJAS32
    [thejas32-testbed.kicad_pcb]
2024-08-12 Trace clearance set exactly to avoid 122 DRCs on THEJAS32
    Any higher than 0.15 mm will cause 122 DRCs exactly on
    THEJAS32 pads. 0.15 mm shows up as 5.90551 mils.
    With this setting DRC errors are 0. Looks like the right
    thing to do to me.
2024-08-12 Review fixes
    Move silkscreen away from CLK trace
    Fix jigglies in traces near THEJAS32
    [thejas32-testbed.kicad_pcb]
2024-08-13 v1.0 10 boards at JLCPCB
2024-08-13 Add PCB views in README for better github ux
2024-09-01 Bringup!
    poweron sample brings up THEJAS32 and dumps the UART log.
2024-09-01 Moved hw related files to new directory
    [1050170001.stp]
2024-09-01 Moved missed files to hw directory
    [thejas32-testbed.kicad_pcb, thejas32-testbed.kicad_sch]
2024-09-01 Blink LED on UART receive
    This serves as an activity indicator, but more importantly,
    serves as indirect "proof" of THEJAS32 system clock.
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2024-09-02 Poweron with automatic baud rate detection.
    It's not bug free, but it "works". Everything isn't thought
    through well for all cases. YMMV.
    [autobaud.c, poweron_autobaud.c]
2024-09-02 3D model of Pico reflects WH, with 2xsingle row socket mount.
    This better reflects how the Pico is being mounted now on the
    board. We mount 2 single row 20 pin sockets. Onto this, Pico
    with headers soldered is pushed.
    [thejas32-testbed.kicad_pcb]
2024-09-02 Rough Mini360 3D model
    The trimpot is much larger in this model. Couldn't find the right
    one. Mini360 looks much fancier in this 3D model.
    [mini360-model.step, thejas32-testbed.kicad_pcb]
2024-09-03 Better Mini360 model
    Got the trimpot model from
    https://grabcad.com/library/evm3e-1
    Fixed the inductor using a fileted cuboid, matching the
    mesurements of the inductor on the mini360. Material
    doesn't match, but that level of accuracy isn't required.
    Also, the MP2307 is a smaller SO package. Fixed that and
    rearranged the passives. The end result is much more
    representative.
    [mini360-model.step]
2024-09-05 Fixed autobaud detection
    Tested all the way from 150 MHz to 62.5 kHz of T32 clock
    [autobaud.c]
2024-09-06 Working uart boot. Hacky, but works
    Based on older autobaud detection, which won't work in all cases.
    Not clean, commiting for archival. Tomorrow is IndiaFOSS - first
    demo so I don't have time to mess around.
    This needs cleanup, but will do for now.
    [uart_boot.c]
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2024-09-06 Timer Interrupt Test
    Toggles LED, dumps toggle count on UART
2024-10-12 Remove unavailable USB connector model
    [thejas32-testbed.kicad_pcb]
2024-10-15 Use VRML model for 3D rendering
    My 3D printed jig generator can't handle STEP files yet.
    Now using the step file converted to VRML with FreeCAD.
    No change in functionality.
    [thejas32-testbed.kicad_pcb]
2024-10-18 Soldering helper jig created with pcb-asm-jig-gen
    I checked the 2x20 header for a nice fit.
    Then generated the jig for the entire board. Saving
    the scad file also as the tool is under heavy
    development.
    Observations of the 3D print:
    PCB fits flush inside the lip. Good thing is that
    the base flexes if some of the components get a bit
    cross. Even with this helper, the single row bergs
    do give some trouble. Some can rock sideways, due to
    the sideways wiggle room available for the legs.
    Single pins sit well before the board is inserted,
    but they also have this tendency to cross, making it
    difficult to fit the board in. There are 8 single
    pin headers on the AtiVEGA board, which kind of makes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
    [jig-solder-bottom.scad]
2024-10-29 Fix height of female headers used with Pico
    The 1x20 female headers available here locally are taller than the
    the 3d model in the design. The plastic shroud is 8.4 mm tall, as
    opposed to 7 mm in PinHeader_1x20_P2.54mm_Vertical
    To correct this, I have moved the headers and the pico upward up
    1.4 mm.
    An alternative was the change the model, but I found this simpler
    for now. While this exposes the pins of the header in the render,
    thus making it look a bit ugly, the actual hardware implementation
    is clearer.
    [thejas32-testbed.kicad_pcb]
